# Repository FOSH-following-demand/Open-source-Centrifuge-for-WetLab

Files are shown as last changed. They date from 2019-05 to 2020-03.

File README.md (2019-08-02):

# An Open Source Centrifuge Design for wetlab based on Polyfuge v.1.0 Design
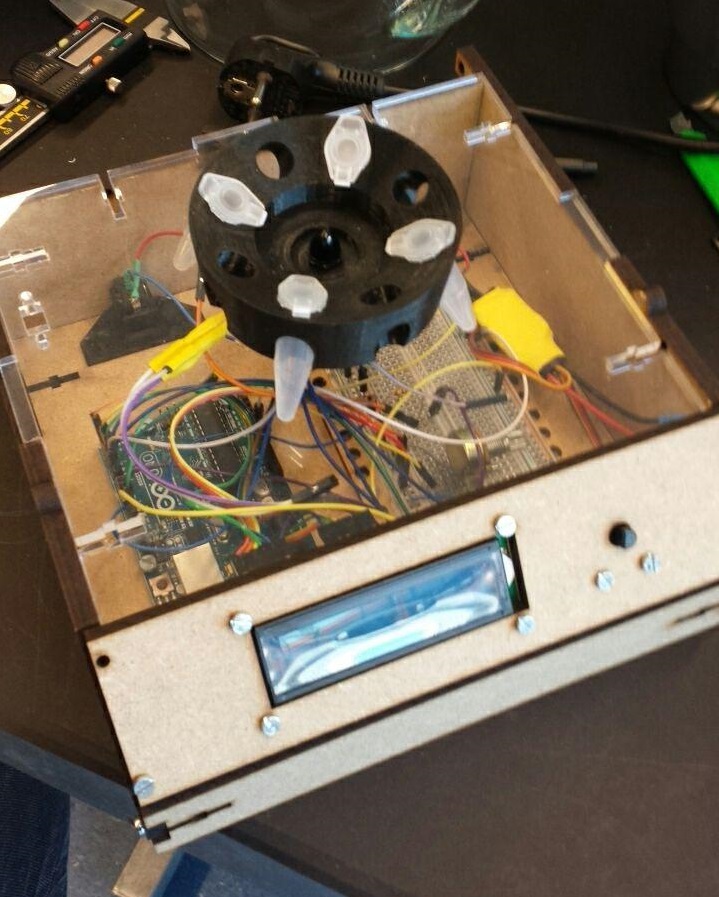
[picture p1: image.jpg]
centrifuge

## Hi! 😄 Welcome to the project
We are working on the design of an open hardware centrifuge based on the following questions:
- What can be improved in existing commercial centrifuges?
- What can be improved in already existing open hardware models?
- **Goal:** Design, improve a key feature based on the answers we got from these two questions.
#### Design approach:
- Replicate a model of open hardware centrifuges.
- Reverse engineer existing broken commercial centrifuges (fix them is possible as part of the process of learning how they work how, and how they can be improved).
- Propose and develop improvements.
    - Currently there are improvements to be made with regard to cooling and safety.

For more information on how we are tackling improvements, ideas, developments [look at the tests-experiments we are working on.](https://github.com/FOSH-following-demand/Open-source-Centrifuge-for-WetLab/tree/master/R%26D/test-cards)

### Current status of the project:
- [Collected data from users](https://docs.google.com/forms/d/1zq9jXL4ni4LQY3pLsI8-8exPlcGnMdUV0iULsLTLMks/viewanalytics). This one already points to interesting features to focus on that open hardware solutions don't consider like cooling, or automatic check  of proper balancing.
- [Ordered parts of Polyfuge version.](https://github.com/FOSH-following-demand/Open-source-Centrifuge-for-WetLab/blob/master/R%26D/Polyfuge-BOM.yml).

### Current phase: Concept generation and prototype design
Based on the research done about centrifuge usage we have defined [requirements](https://github.com/FOSH-following-demand/Open-source-Centrifuge-for-WetLab/tree/master/R%26D/Analysis) and target features to focus on.
## Links
- [Concept for solutions and test cards.](https://github.com/FOSH-following-demand/Open-source-Centrifuge-for-WetLab/tree/master/R%26D/test-cards)
- Find out the concept and associated test cases here.

## About project documentation and folders:
There are two sets of documentation in this repository:
- One that is external and relevant for users. This we try to document carefully and make it easy to understand to others outside the core team. Our final project documentation(the source) will be presented in [this format](https://fosh-following-demand.github.io/Open-source-Centrifuge-for-WetLab/). Be aware that is currently not finished as we haven't released the results yet.
- Another set of documentation is where we keep internal track of our tasks and progress. This one might be too detailed for external users, and even contributors. If you are interested in following up also this set of documentation you need to:
  - Use Atom editor.
  - And install the [.imdone](https://atom.io/packages/imdone-atom) package in Atom.
  - Clone the project.
  - Press `Alt+P`, and you should see the status of project management, tasks and priorities.

## References:
- [Value Proposition prototyping and testing](https://issuu.com/business.model.innovation/docs/vpd_sneakpeek/92)

# Progress documentation
| Week | Products | Call  | Status |
| --- | --- | ----- |---|
| Week 1 | GitHub repo + related_work.md + draft BoM | 1st call with mentor  | Done
| | Went to the lab and did usage research with scientist | | |
| Week 2 | Order BoM + Dev Plan | 2nd call with mentor  | Done |
| | Designed and sent form based on Usage analysis | | Done |
| Week 3 | Updates on development | 3rd call with mentor  | Done |
| | Collecting Data and studying other models (of big and small centrifuges) | | |
|  |Development planned updated, Concept generation | Not able to build because of delayed delivery of components | |
| Week 4 | Got enough results to focus on two key issues: safety and cooling, as we haven't found an open hardware solution with cooling mechanism. Safety and balancing still can be improved in the commercial centrifuges we analyzed | 4th called with mentor  | Done |
| Week 5  | Documenting new concepts and test cases, and updating ordering lists | 5th mentor called |Done|
| Week 6  | Architecture layout for peltier module, teard down and printing of polyfuge parts | 5th mentor called ||

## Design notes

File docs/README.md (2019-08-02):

# Open hardware centrifuge project
## Towards Polyfuge V2.0
  ::: Git repository

Clone, or download [our repo](https://github.com/FOSH-following-demand/Open-source-Centrifuge-for-WetLab) with all the source files.

  :::

A laboratory centrifuge is a piece of laboratory equipment, driven by a motor, which spins liquid samples at high speed. There are various types of centrifuges, depending on the size and the sample capacity. Like all other centrifuges, laboratory centrifuges work by the sedimentation principle, where the centripetal acceleration is used to separate substances of greater and lesser density.
To know more about centrifuges [read here](/SubContent/AboutCentrifuges.md).

## Current design based on Polyfuge V1.0
There are many OH centrifuge designs. For this project we decided to focus on one available open hardware design that was quite comprehensive and complete. This is why we decided to go for [the polyfuge](http://doublegene.com/), developed by doublegene. Find the [repo of Polyfuge V1.0 here](https://github.com/jasonwu2153/Polyfuge-A-DIY-Open-Source-Microcentrifuge-for-Everyone)

## Roadmap for improvements:
- **Design based on Arduino UNO**. We have faced difficulties with the Arduino NANO board specifically
- **Temperature control**. We are adding temperature control with a peltier module and a temperature sensor.
- **Increased speeds**. The current motor is limited in performance with regard to relative centrifuge force.

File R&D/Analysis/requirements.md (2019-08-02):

#Requirements

#### Samples
  - 'x' number of samples
  - sample volume range 'x' to 'z'
  - sample tubed spin under 'z' angle
  - Must be able to keep samples symetric in rotor

#### motor
  - 4700 minimum RPM
  - 10.000 maximum RPM
  - 'z' torque
  - Reliable motor speed with dynamic load variations (is there any specification for this?)
  - Isolation of the motor for
  - Cooling of the motor is required because motor can spin more than 20 mins.

#### Interface / Software
  - Be able to change speed (per how much RPM?)
  - Be able to change run time (per s ?)
  - Show current speed and time on screen

#### Safety
Robustness in this system implies that samples are well fixed to the holder, so that there  are no accidents.

  - Samples must be fixed to rotor
  - The spinning rotor is covered
  - The rotor can't spin while uncovered, can't be uncovered while spinning -> some kind of electric lock needed.
  - Noise limit should be limited to 'x' dB --> limit friction on moving parts.
  - Wiring and small components can't be exposed to moving parts.  
  - Electronic components must be well isolated so that there are no drops falling into them.

#### Embodiment
  - Easy to clean from microbe contamination --> smooth surface, no ridges.
  - Vibration resistant fasteners
  - footing should be stable on a tabletop.
  - Dampening of tremble from rotation is required  --> a counter weight at the bottom?

#### Construction
  - Be able to be put together locally like a kit (is this a requirement?)
  - Be able to be taken apart locally for repair
  -

# Considerations:
## Thermo couple
- One thermocouple should
- Calibration of the thermocouple

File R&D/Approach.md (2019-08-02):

#Documentation:40 Approach to design and development

# Goals of the first iteration
- We build one small centrifuge that kit design ready
- Ready for replication
- High quality documentation
- And reflection on how build the big centrifuge
-

# Approach:
- Case study: Define design questions and problems based on production system, usage, etc.
  - Use the centrifuge as a case study for open hardware products.
  - An example of a question is: why there are machines with 24 slots if daily use only involves 6 samples
  (For )
  - Includes checking patent infringement as well
  - Study current open hardware solution.

## Next steps design - development
- Define target specs:
  - Based on understanding the usability, scale of use, and manufacturing context.

The motor is the component that defines or constrains the whole design of the product, from a technical perspective.

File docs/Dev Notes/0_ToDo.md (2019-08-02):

# To Do:
## Minor issues
- [ ] Change potentiometer in the circuit
- [ ] Make new pcb shield to mount on the arduino

# New upgrades
- [ ] Redesign of the board and the centrifuge with the cooling module

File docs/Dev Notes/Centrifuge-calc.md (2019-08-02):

# Motor Calculation documentation
-[Calculations related to motor in spanish](http://biomodel.uah.es/tecnicas/centrif/centri_calc.htm)

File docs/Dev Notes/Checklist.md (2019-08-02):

# Checklist circuit build
- [ ] Voltage regulator
- [ ] Speed controller
- [ ] IRSensor
- [ ] Rotary Encoder

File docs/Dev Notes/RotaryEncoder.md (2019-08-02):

# Part: Rotary encoder
[Rotary Encoder for control panel with Arduino](https://www.google.com/search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)

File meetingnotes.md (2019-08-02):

## TU Delft meeting 5

- rushing to order everything before deadline and doing calculations for requirements
- tension between desired and possible model, 2 months is little time!!
- In particular, due to delays in ordering parts, and need more time for planning accordingly
- Feedback for next time: better to anticipate at least 1 month do money deadline, and 'force' teams to have clear goals and stages complete
- Will share pictures on work today through Slack

## TU Delft meeting 4

- got space to work!
- ordered parts, billing pending to be sent to Andre

- Discussed ideas for testing and put them into issues: cooling, sensing of cooling, secure parts during movement
- design test to be done, mechanical engineer joining project

- Possible outcome for BFOSH: documentation for hw is better if it's kept simple at first (journaling) instead of OPEN ALL in t=0

- Next: get attention to the issues for user input, keep testing and dev

Next meeting: june 21

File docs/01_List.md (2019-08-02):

# DIY and Open Source Centrifuge list

### [Home made centrifuge](https://www.youtube.com/watch?v=EWWUqkEXJUE)

- [Thingiverse project](https://www.youtube.com/redirect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)

### OpenFuge
- [OpenFuge isntructables](https://www.instructables.com/id/Centrifuge/).
- [OpenFuge Repository](https://www.instructables.com/id/Centrifuge/)
- Very well documented step by step with pictures and breadboard visual schematics.

### BHA Centrifuge
- [BHA Centrifuge Repository](https://github.com/BioHackAcademy/BHA_Centrifuge)

### Polyfuge
- [Polyfuge repository](https://github.com/jasonwu2153/Polyfuge-A-DIY-Open-Source-Microcentrifuge-for-Everyone)

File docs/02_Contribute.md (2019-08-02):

# Contributing guidelines
## Hi! 😸 Thank you very much for reaching us out.
We are looking for contributions of different kind that ranges from incidental but meaningful contributions to extended and close collaboration.

## Things to consider:
- We are focusing in this first iteration on small centrifuge design of 15 ml.
- We are using a reference open hardware project to replicate, test, hack and improve if possible.
-

## These is a list of things you can do in order to contribute to the project:
### User feedback:
- If you are a user of this equipment you can (https:[fill in this form]//docs.google.com/forms/d/e/1FAIpQLScyTZIfLe0GmoX6rdi7wdyzSNGVoP2hBOGGEqeAVn0CZmRDTQ/viewform) and share it with your colleagues.

### Opening github issues for design improvements you have been thinking about:
We always consider each improvement as a hypothesis that needs to be tested.
You can also point to videos, documentation and solutions that support the hypothesis/idea you have in mind. [See this example](https://www.youtube.com/watch?v=9Cuh2msd2lo) as a style guide for test setup.
- If you have ideas about centrifuge solutions features, open an issue and describe the concept/hypothesis considering the following:
  1. How this feature improves the centrifuge design considering:
  1.1. Pains you have already had in your previous experience.
  1.2. Gains your idea has.

  2. Description of the concept.
  3. Preferably describe a test case/experiment [by using the following  markdown template](https://github.com/FOSH-following-demand/Open-source-Centrifuge-for-WetLab/blob/master/R%26D/test-cards/README.md).
  - [You can find an example here:](https://github.com/FOSH-following-demand/Open-source-Centrifuge-for-WetLab/blob/master/R%26D/test-cards/Cooling-led-2.md)

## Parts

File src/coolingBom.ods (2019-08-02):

Part | Description | Quantity | Purchase Link | status | Function
Relays |  |  |  | check at home | 1 for each fan(2), one for the pelter
on/off | On Off switch with power supply |  | https://www.amazon.com/Switch-Supply-Outlet-Socket-Printer/dp/B07B8D1M17 | not ordered
Power supply |  |  |  | in stock
 | N-MOSFET Driver / Output Module |  | https://www.freetronics.com.au/collections/modules/products/n-mosfet-driver-output-module |  | This high-power N-MOSFET module lets you switch high-current loads using a tiny microcontroller. Perfect for controlling that set of traffic lights mounted in your living room! Works brilliantly for automotive projects such as switching high-power 12V lights and high wattage LEDs.

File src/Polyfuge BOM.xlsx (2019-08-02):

Quantity | Manufacturer/Vendor | Part Number | Link | Description
Electrical
1 | Arducam | C0048 | https://www.amazon.com/Arducam-Display-Controller-Character-Backlight/dp/B019D9TYMI | Main LCD for UI display
1 | uxcell | a14011500ux0042 | https://www.amazon.com/Position-Degree-Rotary-Encoder-Button/dp/B00KHTLWU6 | Rotary encoder for control
1 | Elegoo | EL-CB-004 | https://www.amazon.com/Arduino-Elegoo-board-ATmega328P-compatible/dp/B071NMBP4S | Arduino Nano microcontroller
1 | FBApayipa | B01N2U8PK0 | https://www.amazon.com/FBApayipa-Solder-Rocker-Switch-Toggle/dp/B01N2U8PK0?s=electronics | Boat Rocker Switch for ON/OFF
1 | GenBasic | 4330127279 | https://www.amazon.com/GenBasic-Female-Solderless-Breadboard-Prototyping/dp/B01L5ULRUA?s=electronics | Pack of F to F headers for circuit connections
1 | BLHeli | B01D3127NU | https://www.amazon.com/Hobbypower-BLHeli-Controller-QAV210-Quadcopter/dp/B01D3127NU | 12A ESC for centrifuge motor
1 | EMAX | B00SYH8NXC | https://www.amazon.com/Crazepony-MT2204-Brushless-Multirotor-Quadcopter/dp/B00SYH8NXC | Brushless motor for centrifuge rotor
1 | Orcity | B01MQ48T2V | https://www.amazon.com/2-54mm-Breakaway-Female-Connector-Arduino/dp/B01MQ48T2V | Pack of breakaway M and F pins for boards
1 | SUNKEE | 1361783 | https://www.amazon.com/SUNKEE-TCRT5000L-TCRT5000-Reflective-Transistor/dp/B008A3VP6M | IR sensor for lid safety interlock
1 | ALED LIGHT | B013SSU92Y | https://www.amazon.com/gp/product/B013SSU92Y/ref=oh_aui_detailpage_o00_s00?ie=UTF8&psc=1 | 2A Power adapter (US)
1 | eBoot | EXPSFD005794 | https://www.amazon.com/eBoot-LM2596-Converter-3-0-40V-1-5-35V/dp/B01GJ0SC2C | LM2596 Voltage Regulator
1 | uxcell | a15071300ux0341 | https://www.amazon.com/a15071300ux0341-Terminals-Potentiometer-Adjustable-Resistor/dp/B015AUI2TK?s=industrial | 200 Ohm trim potentiometer for LCD contrast
2 | E-Projects | B071439J4B | https://www.amazon.com/Projects-10EP51410K0-10k-Resistors-Pack/dp/B071439J4B?s=industrial | 10k Ohm resistors for circuit board
1 | E-Projects | B0725G2WM7 | https://www.amazon.com/Projects-100EP514100R-100-Resistors-Pack/dp/B0725G2WM7?s=industrial | 100 Ohm resistor for circuit board
1 | DoubleGene | N/A | See open-source files | Open-Source Polyfuge PCB
1 | ZRAMO | UK-HM023 | https://www.amazon.com/ZRAMO-5-5x2-1mm-Adapter-Connector-Security/dp/B06XXCTNX5 | Barrel Jack adapter for power supply
Mechanical
1 | DoubleGene | N/A | See open-source files | Open-Source Polyfuge centrifuge rotor
1 | DoubleGene | N/A | See open-source files | Open-Source laser cut or 3D-printed frame components
50 | McMaster-Carr | 92005A128 | https://www.mcmaster.com/#catalog/123/3033/=178lzno | 20mm M3 Steel Philips Rounded Screw
50 | McMaster-Carr | 90591A250 | https://www.mcmaster.com/#catalog/123/3210/=178m0rv | M3 Steel Hex Nut
10 | McMaster-Carr | 91166A210 | https://www.mcmaster.com/#catalog/123/3254/=178m1nk | M3 Steel Washer
50 | McMaster-Carr | 90133A005 | https://www.mcmaster.com/#standard-rubber-washers/=19akq7h | M3 Rubber Washer
4 | McMaster-Carr | 92005A120 | https://www.mcmaster.com/#machine-screws/=17ptixe | 10mm M3 Steel Philips Rounded Screw
4 | ROK Hardware | SCB03-144 | https://www.amazon.com/Rok-Hardware-Cabinet-Furniture-Diameter/dp/B00K6RZ9Q2 | Furniture bumpers to dampen vibrations on bottom of unit
Other (Raw Materials for Frame and Rotor)
1 | Hatchbox | B00J0ECR5I | https://www.amazon.com/HATCHBOX-3D-Filament-Dimensional-Accuracy/dp/B01N53KX79 | PLA Filament for printing rotor and encoder knob (use 20% infill or higher)
24" x 20" | McMaster-Carr | 8505K748 (https://www.mcmaster.com/) | https://www.mcmaster.com/#clear-impact-resistant-plastic/=1c43uxq | 3/16" Acrylic for frame pieces (purchase from local companies/stores for cheaper prices)

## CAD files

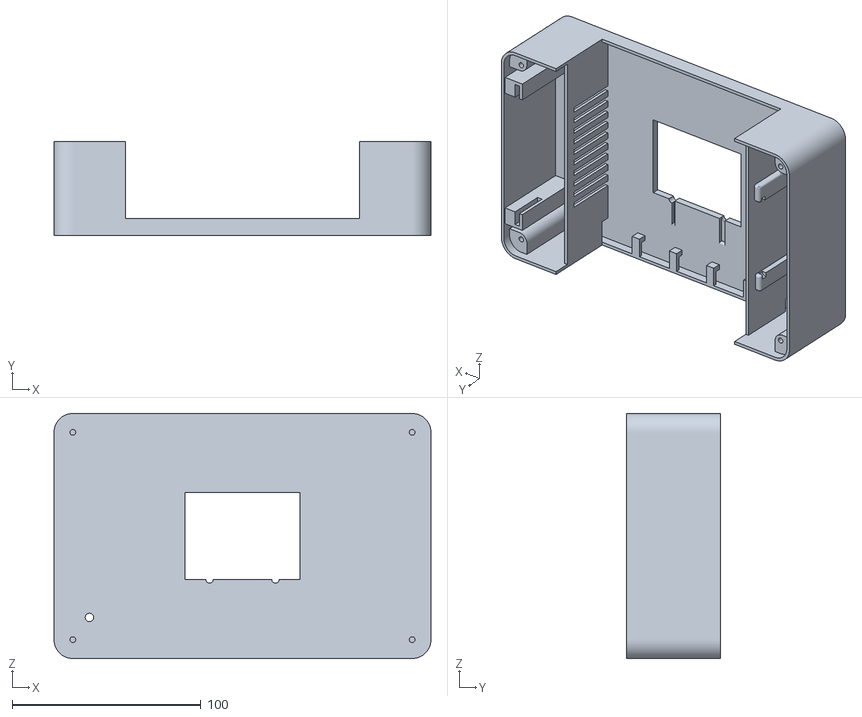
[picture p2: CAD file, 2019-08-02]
R&D/design-tests-setups/Cooling-lid-02/mini-fridge/cover_2.stl
200.0 x 50.0 x 130.0

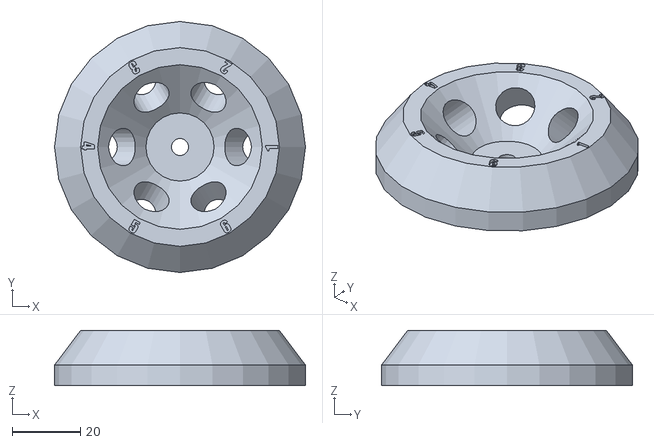
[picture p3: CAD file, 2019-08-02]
R&D/design-tests-setups/Cooling-lid-02/V2_Rotor.stl
73.6 x 73.6 x 16.1

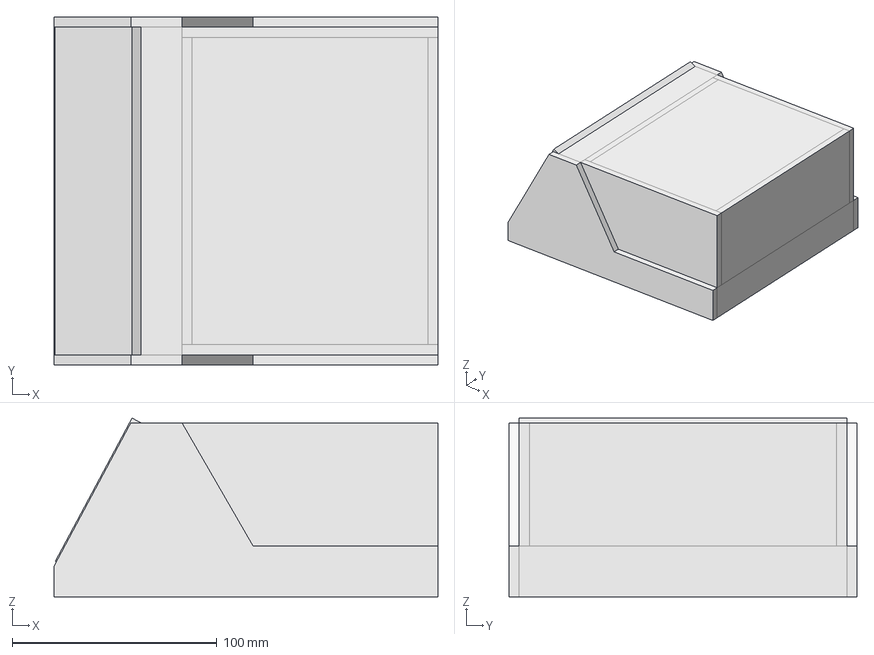
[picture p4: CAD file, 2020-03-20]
R&D/polyfuge 1.2/sheet model_no cut.FCStd
187.5 x 170.0 x 87.4 mm

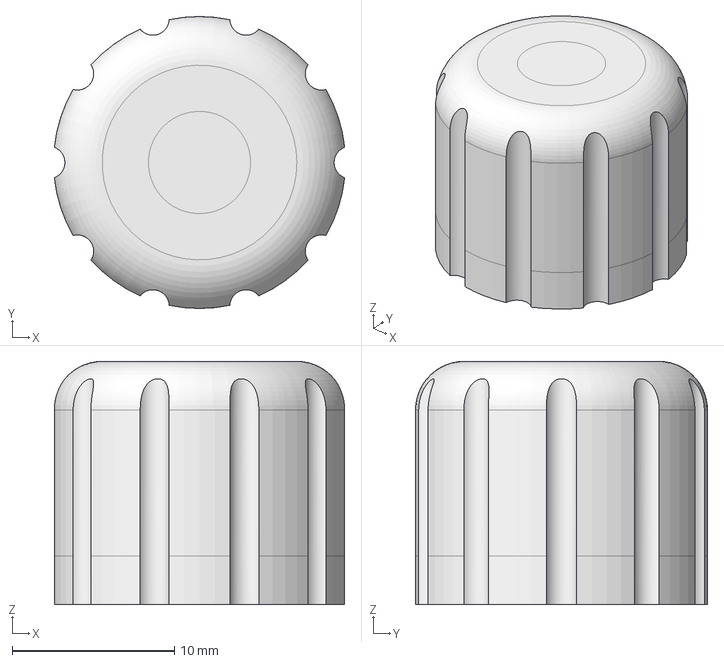
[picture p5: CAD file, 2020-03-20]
src/knob v3.FCStd
17.9 x 18.0 x 15.0 mm

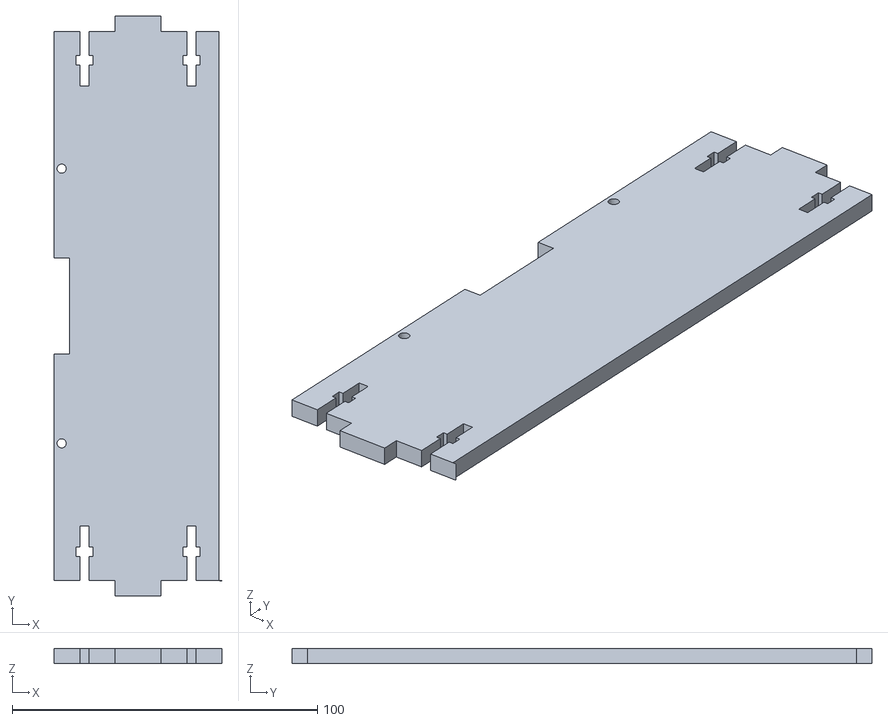
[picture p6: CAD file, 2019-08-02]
src/Polyfuge STL Files (For 3D-Printing)/Pieces/Top Back Panel.stl
55.0 x 190.0 x 5.00

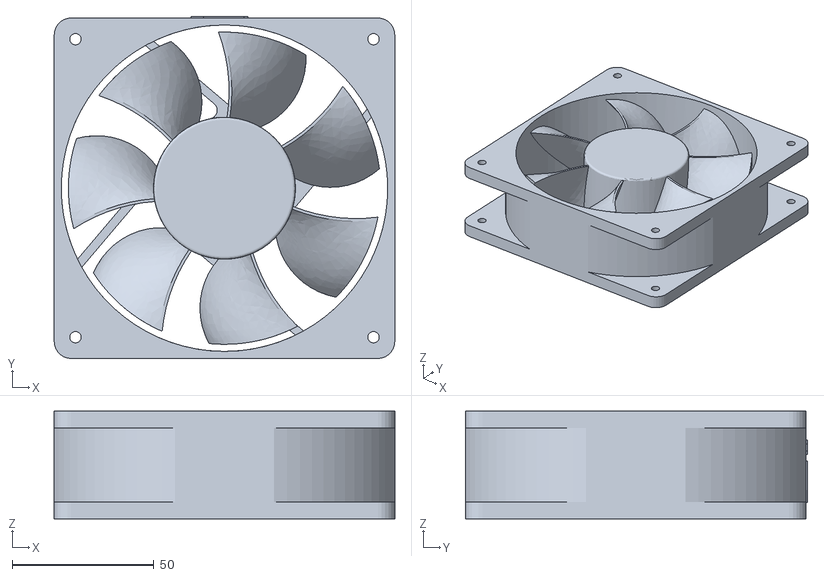
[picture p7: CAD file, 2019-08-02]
R&D/design-tests-setups/Cooling-lid-02/4-inch-fan.stl
120.0 x 120.5 x 38.0

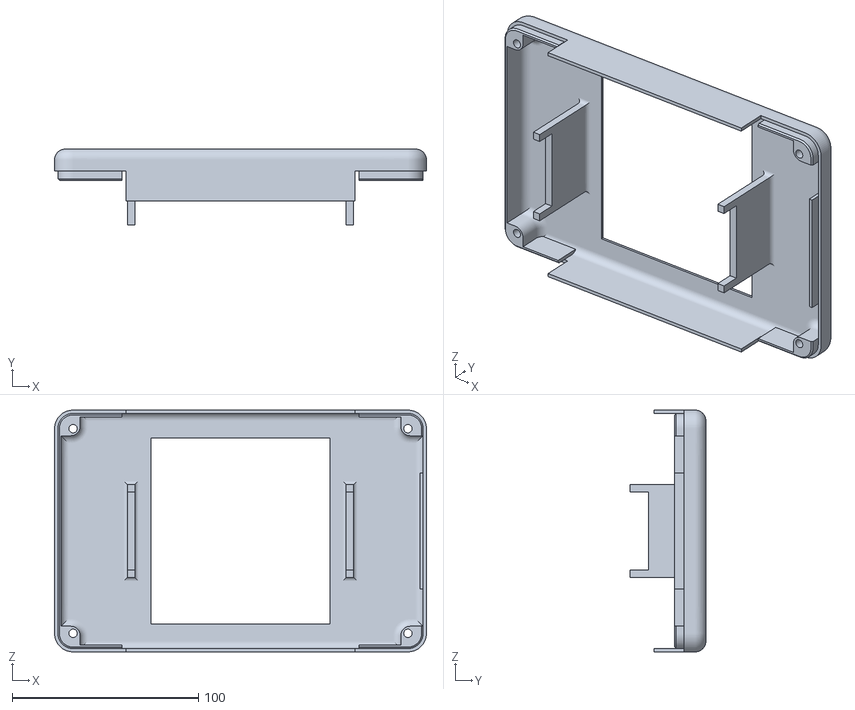
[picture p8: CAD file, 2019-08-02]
R&D/design-tests-setups/Cooling-lid-02/mini-fridge/cover.stl
200.0 x 40.8 x 130.0

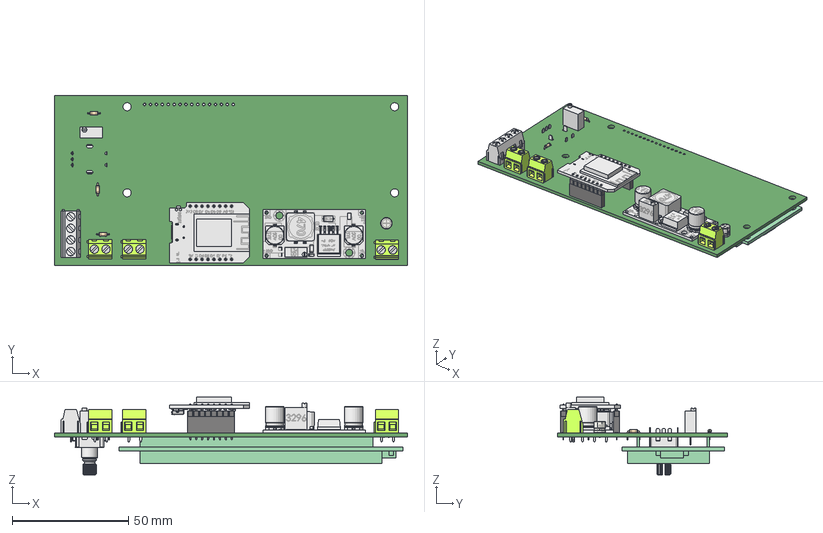
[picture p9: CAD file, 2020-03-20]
R&D/polyfuge 1.2/PCB.FCStd
151.8 x 73.0 x 33.4 mm

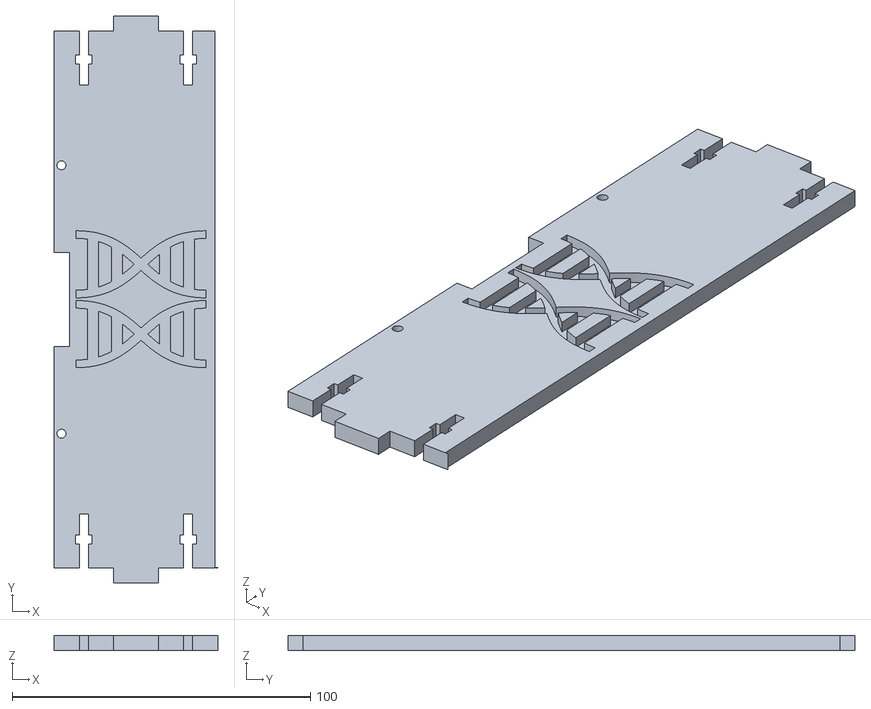
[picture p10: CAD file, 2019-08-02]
src/Polyfuge STL Files (For 3D-Printing)/Pieces/Top Front Panel (With Design DoubleGene).stl
55.0 x 190.0 x 5.00

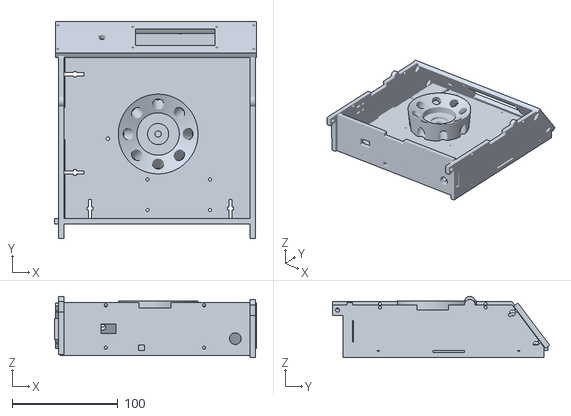
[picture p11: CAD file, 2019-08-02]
R&D/design-tests-setups/Cooling-lid-02/polyfuge-ref4.stl
191.0 x 205.6 x 58.0

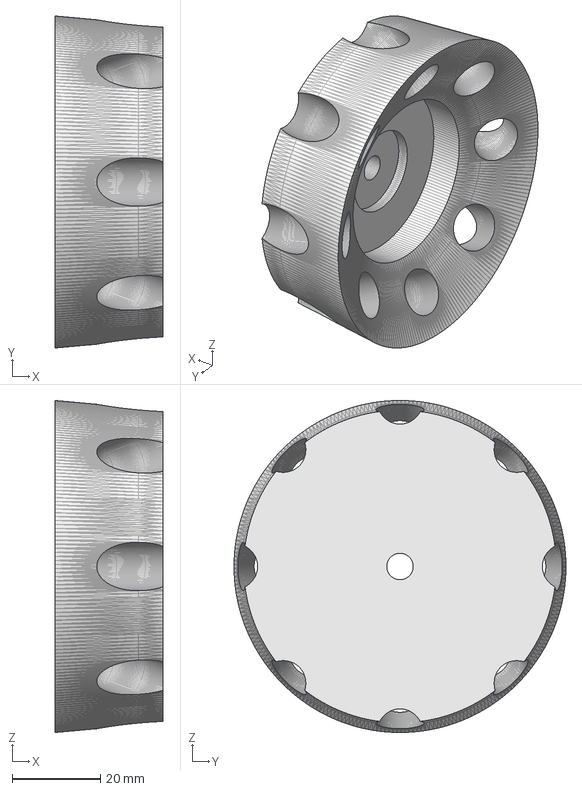
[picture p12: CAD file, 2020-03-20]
R&D/polyfuge 1.2/rotor.FCStd
24.4 x 75.3 x 75.3 mm

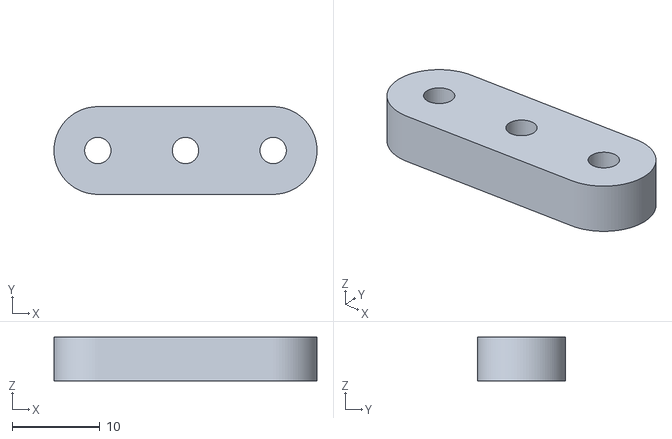
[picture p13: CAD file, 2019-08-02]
src/Polyfuge STL Files (For 3D-Printing)/Pieces/Side Panel Hinge.stl
30.0 x 10.0 x 5.00

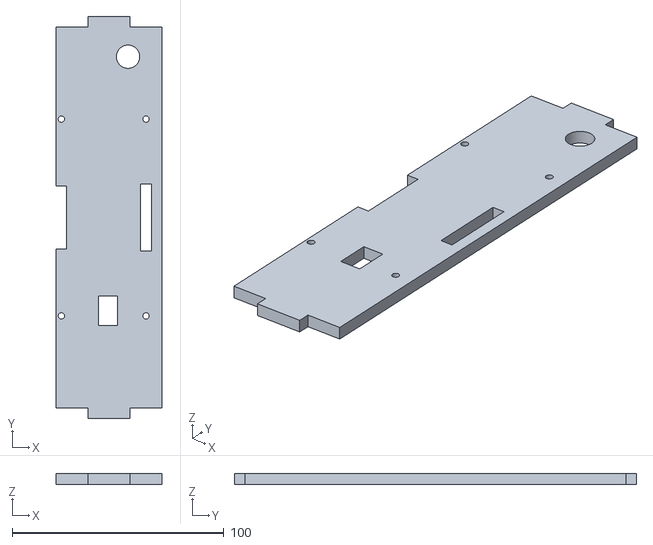
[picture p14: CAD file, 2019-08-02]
src/Polyfuge STL Files (For 3D-Printing)/Pieces/Back Panel.stl
50.0 x 190.0 x 5.00

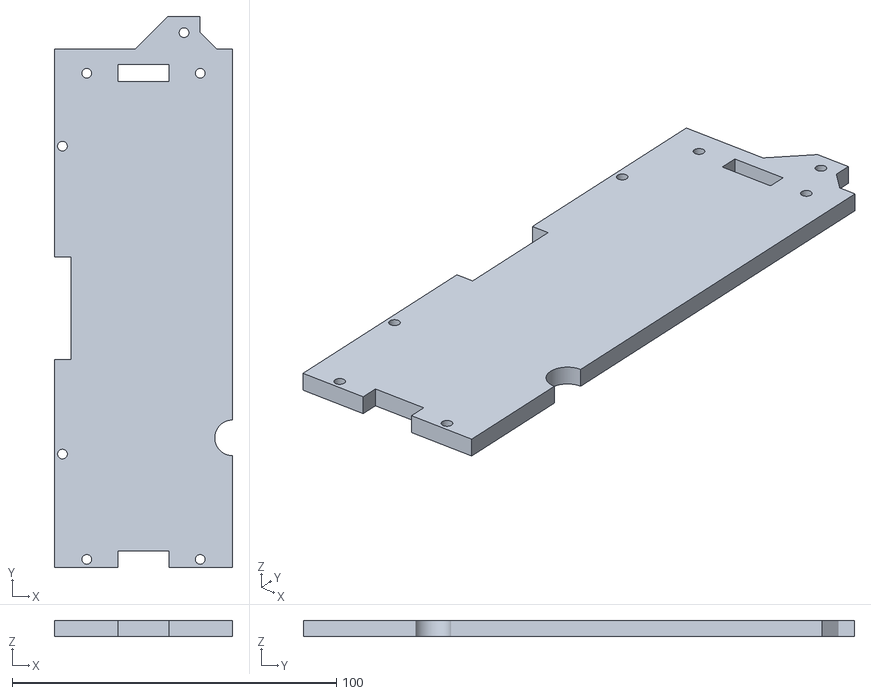
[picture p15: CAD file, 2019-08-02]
src/Polyfuge STL Files (For 3D-Printing)/Pieces/Top Side Panel (NO IR BLOCKER).stl
55.0 x 170.0 x 5.00

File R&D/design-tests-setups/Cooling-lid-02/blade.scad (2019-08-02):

//!OpenSCAD

// Thickness of the blade overall
Overall_Thickness = 6.2;
// Outer Diameter with blades (default 37mm)
Outer_Diameter_Blades = 37;
// Thickness of the blades (default 1mm)
Thickness_Blades = 0.8;
// Amount of blades (default 9)
Amount_Blades = 6;
// The angle with which the blades are bowed (default 50°)
Bowing_Blades = 45;
// The angle of the blades (default 50°)
Angle_Blades = 45;
// Inner Diameter of the Body (default 22.6mm)
Inner_Diameter_Body = 10;
// Thickness of the body parts (default 1.2mm)
Thickness_Body = 1;
// The diameter of the axle hole (default 1.8mm)
Axle_Diameter = 2;

// Circle Resolution
$fn = 64;

// Some helping parameter
Length_Blades = (Outer_Diameter_Blades - Inner_Diameter_Body) / 2;
Remaining_Angle = (90 - Bowing_Blades) / 2;
Radius_Blades = Overall_Thickness / (cos(Remaining_Angle) - sin(Remaining_Angle));
translate([0, 0, (Overall_Thickness / 2)]){
  union(){
    difference() {
      union(){
        difference() {
          cylinder(r1=(Inner_Diameter_Body / 2 + Thickness_Body), r2=(Inner_Diameter_Body / 2 + Thickness_Body), h=Overall_Thickness, center=true);

          translate([0, 0, (Thickness_Body / 2)]){
            cylinder(r1=(Inner_Diameter_Body / 2), r2=(Inner_Diameter_Body / 2), h=(Overall_Thickness - Thickness_Body), center=true);
          }
        }
        translate([0, 0, (-1 * (Overall_Thickness / 2 - (Thickness_Body + 0.5)))]){
          cylinder(r1=(Axle_Diameter / 2 + 1), r2=(Axle_Diameter / 2 + 1), h=1, center=true);
        }
      }

      translate([0, 0, (-1 * (Overall_Thickness / 2 - 2.7))]){
        cylinder(r1=(Axle_Diameter / 2), r2=(Axle_Diameter / 2), h=5, center=true);
      }
    }
    intersection() {
      for (i = [0 : abs(360 / Amount_Blades) : 360]) {
        rotate([0, 0, i]){
          translate([((Inner_Diameter_Body + Length_Blades) / 2), 0, 0]){
            rotate([0, 90, 0]){
              Mean_X = Radius_Blades * (cos(Angle_Blades) * cos((Bowing_Blades / 2)));
              Mean_Y = Radius_Blades * (sin(Angle_Blades) * cos((Bowing_Blades / 2)));
              translate([(-1 * Mean_X), (-1 * Mean_Y), 0]){
                for (j = [Angle_Blades - Bowing_Blades / 2 : abs(Bowing_Blades / 20) : Angle_Blades + Bowing_Blades / 2]) {
                  translate([(Radius_Blades * cos(j)), (Radius_Blades * sin(j)), 0]){
                    rotate([(-1 * (atan((sin(j) * Radius_Blades - Mean_Y) / ((Length_Blades + Inner_Diameter_Body) / 2 + Thickness_Body)))), 0, 0]){
                      rotate([0, 0, j]){
                        cube([Thickness_Blades, Thickness_Blades, Length_Blades], center=true);
                      }
                    }
                  }
                }

              }
            }
          }
        }
      }

      cylinder(r1=(Outer_Diameter_Blades / 2), r2=(Outer_Diameter_Blades / 2), h=Overall_Thickness, center=true);

    }
  }
}

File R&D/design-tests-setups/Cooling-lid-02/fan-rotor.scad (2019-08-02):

module rotor(){
  translate([18,258,0])
  import("V2_Rotor.stl", convexity=3);
  $fn=64;
  for(i=[0:5]){
    rotate(i*60,[0,0,1])
    translate([0,25,0])
    rotate([0,20,30])cube([2,13,17]);
  }
}

/* rotor(); */
module sample(){
  difference(){
    cylinder(h=20, r=9, center=true);
    cylinder(h=30, r=5.6, center=true);
  }
}

for(i=[0:5]){
  rotate(i*60,[0,0,1])
  union(){
  translate([-25,0,2])rotate([0,45,0])sample();
  translate([12,20,0])rotate([0,-60,0])cube([2,20,27]);
  }
}


module fan(){
  import("4-inch-fan.stl");
}

/* scale(0.85)translate([0,0,0])color("DarkSlateGray",0.25)fan(); */

/* translate([0,60,0])
union(){
sample();
translate([12,-5,2])rotate([0,-50,0])cube([2,27,20],center=true);
} */

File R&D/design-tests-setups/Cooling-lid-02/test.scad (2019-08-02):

module cooling_surface(half){
    module object(){
    difference(){
    color("red")
    difference(){
    cylinder(h = 30, r1 = 42, r2 = 42, center = true);
    translate([0,0,-12])
    cylinder(h = 50, r1 = 40, r2 = 40, center = true);
    }
    cube([42,42,40], center=true);
  }
}
    if (half==true){
      difference(){
      object();
      cube([90,90,90]);
      }
    }
    else{
      object();
    }
}

module peltier(){
  color("grey")
  cube([40,40,4], center=true);
}

module fan(){
  import("4-inch-fan.stl");
}

// cooling_surface();
module rotor(){
  translate([18,258,0])
  import("V2_Rotor.stl", convexity=3);
}

module lid(){
  rotate([90,0,0])
  translate([0,-50,0])
  import("mini-fridge/cover.stl");
  translate([0,0,-53])
  rotate([90,0,0])
  import("mini-fridge/cover_2.stl");
}

module polyfuge(){
  import("polyfuge-ref4.stl");
}


/* difference(){ */
  union(){
  rotor();
  translate([0,0,10])cooling_surface();
  translate([0,0,27])peltier();
  union(){
    scale(0.85)translate([0,0,80])color("DarkSlateGray")fan();
    translate([0,0,80])lid();
  }
  translate([95,-80,-30])color("DodgerBlue")polyfuge();

  }
/* translate([-50,0,40])cube([100,150,100],center=true);
} */

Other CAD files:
src/knob3.stl
src/Polyfuge STL Files (For 3D-Printing)/Pieces/IR Blocker.stl
src/Polyfuge STL Files (For 3D-Printing)/Pieces/Base.stl
src/Polyfuge STL Files (For 3D-Printing)/Pieces/Top Panel.stl
src/Polyfuge STL Files (For 3D-Printing)/Pieces/Front Panel.stl
src/Polyfuge STL Files (For 3D-Printing)/Pieces/Rotor V2.stl
src/Polyfuge STL Files (For 3D-Printing)/Pieces/Rotor.stl
src/Polyfuge STL Files (For 3D-Printing)/Pieces/Side Panel (No Mounts).stl
src/Polyfuge STL Files (For 3D-Printing)/Pieces/Side Panel (Optical).stl
src/Polyfuge STL Files (For 3D-Printing)/Pieces/Side Panel (USB).stl
src/Polyfuge STL Files (For 3D-Printing)/Pieces/Top Side Panel (IR Blocker).stl
src/Polyfuge STL Files (For 3D-Printing)/Pieces/Top Top Panel.stl
src/Polyfuge STL Files (For 3D-Printing)/Pieces/knob.stl

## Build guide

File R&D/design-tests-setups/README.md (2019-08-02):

# TEST:50 Name of the test
#### Name: Person
#### Date:

## 1. Concept-for-solution:
Describe what is your solution-hypothesis/feature and how you think it should works.

## 2. To verify that we will do the following test:
## Checklist for experiment:
- [ ] Use an image to explain the setup
- [ ] What are the materials needed.
- [ ] Which materials need to be ordered
- [ ] How expensive is it roughly
Describe the experiment/ test as detailed as possible.

## 3. What are you going to measure
## Checklist:
- [ ] How much data
- [ ] How much time does it takes

## 4. Your experiment is successful if:
Define a target threshold, set of criterion that validates or invalidates the experiments.

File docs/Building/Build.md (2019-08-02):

# Building

## Circuit Build
::: tip
Be aware that this design will be also developed in a PCB.

But you can also replicate it using a regular breadboard.

 :::

Centrifuge schematic

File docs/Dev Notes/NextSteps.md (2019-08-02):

# Next Step Assembly
- Add the code for the sensor to run the motor

## Notes for new design
- Bigger power supply
- New Breakboard for powersupply that powers bigger and cooling module.
- New circuit board for the polyfuge with Arduino Uno

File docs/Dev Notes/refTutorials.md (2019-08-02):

# References and tutorials
## LCD tutorial

- [Arduino LCD Tutorial](https://howtomechatronics.com/tutorials/arduino/lcd-tutorial/).

- [LM 2596 DC -DC Buck converter | Adjustable step down module | specifications -Application](https://www.youtube.com/watch?v=QPntXt8Ea3s).

- [How does a brushless motor works](https://www.youtube.com/watch?v=uOQk8SJso6Q)

## Motor control
- [Control brushless motor with Arduino](https://www.youtube.com/watch?v=DTOK6CgXRXg)
- [Brushless motor control with Arduino Nano](https://www.youtube.com/watch?v=neU6vPDGOBA)

## Voltage regulator for board
The board takes a maximum of 5.5 Volts, there fore a voltage regulator is needed. We are currently using a [LM2596 Voltage Regulator](https://www.minikits.com.au/LM2596-PSU-01).
- [Video review of the regulator](https://www.youtube.com/watch?v=6LTxJWsn1HQ)

## Cooling module with arduino
- [Peltier Controlled From An Android App](https://create.arduino.cc/projecthub/abetoo/peltier-controlled-from-an-android-app-e59617).
- [Fridge project with peltier part 1](https://www.youtube.com/watch?v=1Kp_yWY2tdU).
- [Fridge project with peltier part 2](https://www.youtube.com/watch?v=BHFI9nGY8Qs).
- [Relay module for arduino](https://randomnerdtutorials.com/guide-for-relay-module-with-arduino/).
- [Arduino temperature controller](https://www.instructables.com/id/Arduino-Temperature-Controller/)

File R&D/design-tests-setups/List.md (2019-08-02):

In this document we collect all the hypothesis related to product improvements, pains and gains from our analysis. This analysis includes the state of the art of current open hardware and proprietary centrifuges, as wel.

#Hypothesis:30 ## Doubled motor centrifuge
A model like the one in the drawing can be more cost effective...

#TEST:50 Calculate costs for doubled motr centrifuge
Assuming the following

#Hypothesis:0 ## An industrial standard casing that can be adapted re-purposed
- There might be casings, and chasis solutions that are generic and can be used for the centrifuge.

#Hypothesis:20 ## Casing made of [vacuum forming](https://en.wikipedia.org/wiki/Vacuum_forming)
- We can make already an improvement to this centrifuge by changing the casing design.

#TEST: ## Can we accurately balance a rotor with one very sensitive sensor?
- Angle sensor can be a good potmeter with a rod that brushes the bottom of the rotor.
- The rotor makes one slow spin before turning on the program, any change in the potmeter's resistance means that the rotor isn't balanced.
- Or we could have it reading throughout operation of the centrifuge.
- Or two springloaded potmeters opposite of eachother, and the difference is calculated.
- Other sensor option: contact sensor
-

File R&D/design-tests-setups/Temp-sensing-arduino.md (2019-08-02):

# Temperature Sensing with K+Thermocouple and Arduino
[See the video here](https://www.youtube.com/watch?v=0KJ8H_SUWp0)

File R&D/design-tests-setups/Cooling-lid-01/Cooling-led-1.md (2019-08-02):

#TEST:30 ## Cooling led before centrifuging
#### Name: Jose
#### Date: 7-6-2019

## 1. Concept-for-solution:
A peltier element `3` can be placed on a metal surface `1` that is in direct contact with the samples reservoir`4`. The samples cooled via this setup and the cooling mechanism decouples before the centrifuge starts to rotate.

## 2. To verify that we will do the following test:
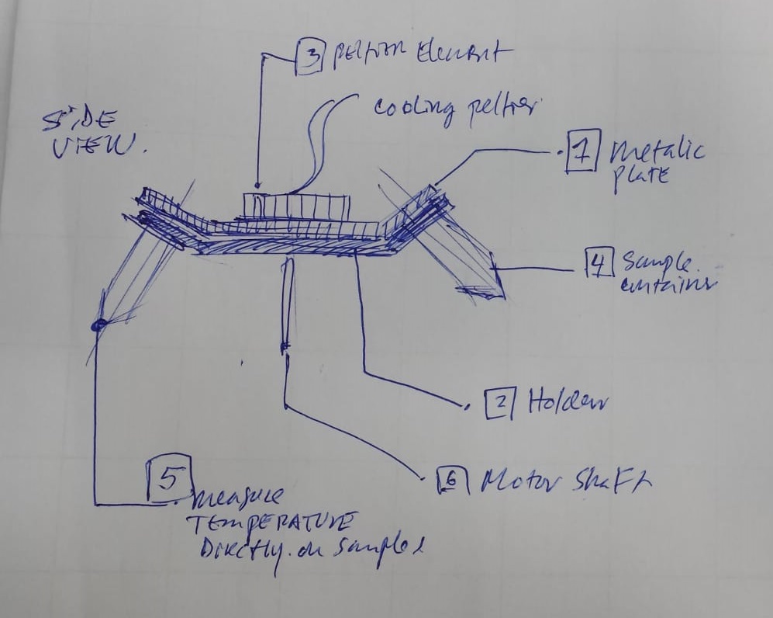
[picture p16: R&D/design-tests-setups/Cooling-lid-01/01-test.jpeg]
experiment

- The setup is going to be isolated in a box.
- Metalic plate is in contact with each sample.
- There are 12-24 samples in the test case.
- A sensor senses ambient temperature in the box.
- Another sensor measures directly on one of the samples.

### Checklist for experiment:
- [ ] Use an image to explain the setup
- [ ] What are the materials needed.
  - temperature sensor to measure directly the sample reservoir
- [ ] Which materials need to be orderedpre
- [ ] How expensive is it roughly

## 3. What are you going to measure
- Measure inner temperature in sample
  - Must calculate the inner temperature of the sample, not the outer of  the sample reservoir. Calculate this based on the material.
  - Heat transfer considerations.
- Measure samples also after being centrifuged.

## 4. Your experiment is successful if:
- The temperature doesn't go bellow 4 degrees
- The temperature stays stable for

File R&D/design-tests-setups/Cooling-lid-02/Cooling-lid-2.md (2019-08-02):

# Peltier on led floating close to sample
#### Name: Santosh
#### Date:

## 1. Concept-for-solution:
The peltier doesn't touch the sample. It starts cooling when it rotates, air is cooled with the peltier and that air cools the sample. The concept the faster it rotates the faster it will cool down. Thermo couple will measure the temperature and will compare to the set value of temperature.
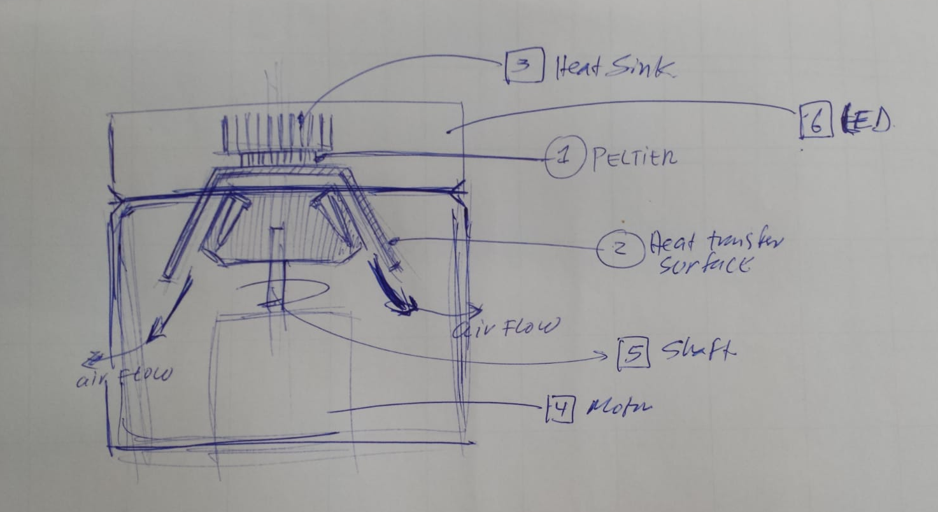
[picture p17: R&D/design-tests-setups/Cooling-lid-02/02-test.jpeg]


## 2. To verify that we will do the following test:
## Checklist for experiment:
Based on the temperature range (what thermo couple is able to measure), we decide the type of it.

## Materials:
- [K type](https://en.wikipedia.org/wiki/Thermocouple), should do the job. Is the cheapest and most commonly used.
- [Cooling kit that incldes peltier, heatsink, fan,and more.](https://www.amazon.de/dp/B01M5DX5KT?tag=tv-auto-20)
- Power Supply (Not specified yet)
## 3. What are you going to measure
## Checklist:
- [ ] How much data
- [ ] How much time does it takes

## 4. Your experiment is successful if:
- We are able to cool the samples in less than 5 minutes to the target temperature set by the user.
- The temperature of the samples remain constant.

# Implementation notes
## Usage considerations:
3. The chamber needs to be already cooled before we put the samples.
2. Therefore in this concept, the user would have to first cool the system,
3. Then open the led to place the sample.
4. And start centrifuging.

## Architecture and layout model test:


## How to measure temperature
**Options/Ideas:**

a. Wireless temperature sensor touching one of the samples, mounted on the rotor.

b. Meausre right after the cool process placing thermo coupler on top of the sample

## References
- [Building your own mini fridge](https://hackaday.com/2015/04/03/building-your-own-mini-fridge/).
- [Peltier Thermoelectric Cooler](https://www.youtube.com/watch?v=jCMDuTR-mqY&t=47s)
- [Peltier Module Cooling](https://www.youtube.com/watch?v=9Cuh2msd2lo).

# Ideas


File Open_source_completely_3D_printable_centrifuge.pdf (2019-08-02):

Instruments 2019, 3, 30; doi:10.3390/instruments3020030 | www.mdpi.com/journal/instruments

Article

# Open Source Completely 3-D Printable Centrifuge

Salil S. Sule ¹, Aliaksei L. Petsiuk ² and Joshua M. Pearce ²,3,4,*

1 | Department of Mechanical Engineering–Engineering Mechanics, Michigan Technological University,
| Houghton, MI 49931, USA; ssule@mtu.edu
2 | Department of Electrical & Computer Engineering, Michigan Technological University, Houghton, MI
| 49931, USA; apetsiuk@mtu.edu
3 | Department of Material Science & Engineering, Michigan Technological University, Houghton, MI 49931,
| USA
4 | Department of Electronics and Nanoengineering, School of Electrical Engineering, Aalto University, Espoo,
| FI-00076, Finland
* | Correspondence: pearce@mtu.edu or joshua.pearce@aalto.fi; Tel.: +01-906-487-1466

Received: 13 May 2019; Accepted: 15 May 2019; Published: 18 May 2019

Abstract: Centrifuges are commonly required devices in medical diagnostics facilities as well as scientific laboratories. Although there are commercial and open source centrifuges, the costs of the former and the required electricity to operate the latter limit accessibility in resource-constrained settings. There is a need for low-cost, human-powered, verified, and reliable lab-scale centrifuges. This study provides the designs for a low-cost 100% 3-D printed centrifuge, which can be fabricated on any low-cost RepRap-class (self-replicating rapid prototyper) fused filament fabrication (FFF)-or fused particle fabrication (FPF)-based 3-D printer. In addition, validation procedures are provided using a web camera and free and open source software. This paper provides the complete open source plans, including instructions for the fabrication and operation of a hand-powered centrifuge. This study successfully tested and validated the instrument, which can be operated anywhere in the world with no electricity inputs, obtaining a radial velocity of over 1750 rpm and over 50 N of relative centrifugal force. Using commercial filament, the instrument costs about U.S. $25, which is less than half of all commercially available systems. However, the costs can be dropped further using recycled plastics on open source systems for over 99% savings. The results are discussed in the context of resource-constrained medical and scientific facilities.

Keywords: 3-D printing; additive manufacturing; biomedical equipment; biomedical engineering; centrifuge; design; distributed manufacturing; laboratory equipment; open hardware; open source; open source hardware; medical equipment; medical instrumentation; scientific instrumentation

### 1. Introduction

Adopting an open-source model of technological development enables equipment designers to quickly build upon one another’s work [1–3]. This democratization of design assists many individuals in effectively working together by making a range of contributions over time using open source tools [4–6]. Some of the most effective tools for encouraging widespread open hardware designs are themselves means of digital distributed manufacturing [7,8]. For example, the open source nature of the self-replicating rapid prototyper (RepRap) 3-D printer [9–11] has radically increased the accessibility of additive manufacturing (AM) while eviscerating the costs of rapid prototyping and product fabrication [12–15]. RepRaps and derivative commercial variants have obtained mechanical 3-D printed part strengths [16] and qualities of interest to the scientific community [17]. Many open source digitally fabricated devices are now widely used by the scientific community [18–20]. For example, 3-D printed parts are used in chemical mixing [2,20–24], optical and mechanical testing [24–26], water quality testing [27–30], and syringe pumping [31–34] (which

Instruments 2019, 3, 30 | 2 of 19

can be in turn used for more complicated systems such as fabricating microfluidics and metafluidics [35–37] or slot die deposition [38]). In addition to offering scientists the ability to customize their equipment and fully control their function, open source 3-D printable tools are much less expensive than equivalent or inferior commercial systems [18,39,40]. In general, these economic savings are greater for a high percentage of the components able to be 3-D printed [41]. A high return on investment (ROI) is realized for distributed manufacturing with commercial polymer 3-D printing filament based on downloaded substitution values [42,43]. In order to continue to “stand on the shoulders of giants” in open hardware [44], this paper describes the design of an open source completely 3-D printable centrifuge.
A centrifuge is a machine that holds rapidly rotating containers while applying centrifugal force to the fluids inside the containers to separate them based on different densities. Centrifuges are commonly required devices in medical diagnostics facilities because they are used for determining the concentration of pathogens and parasites in biological fluids, DNA preparation, and the extraction of plasma from the whole blood needed for immunoassays or hematocrit analysis. There are many commercial laboratory centrifuges and a number of open source variants, including the open analytical ultracentrifugation (AUC) [45], the laser cut OpenFuge [46], the Polyfuge [47], several variations of minicentrifuges [48–50], and one that uses a Dremel and 3-D printed chuck [51]. These open hardware tools do provide for those without access to more expensive proprietary tools [52], but they all depend on access to electricity. Unfortunately, an estimated 1.1 billion people (e.g., 14% of the global population) do not have access to electricity [53]. In addition, even many of those that do have access to electricity have unreliable power. For example, in Nigeria, power outages over extended times have forced a shift to expensive and polluting captive power generation in the majority of businesses [54]. To overcome this challenge of reliable electric power, several open source hand-powered centrifuges have been developed, including the paperfuge [55], a salad spinner centrifuge [56], and an eggbeater centrifuge [57]. All of these are functional, but they lack either large volume capabilities [55] or reliability. To overcome this, several companies have commercialized relatively robust hand-crank centrifuges, which cost U.S. $60–100 [58,59]. These costs can still be prohibitive, and as centrifugation is the first key step in most diagnostic assays [60], there is a need for a low-cost, portable, human-powered centrifuge that can be used by scientists and medical personnel, especially for diagnostics in resource-limited environments [60–63].
This study provides the designs for a low-cost 100% 3-D printed centrifuge apparatus, which can be fabricated on any low-cost RepRap-class fused filament fabrication (FFF)- or fused particle fabrication (FPF)-based 3-D printer. In addition, a validation procedure for quantifying the rotational speed is provided, which makes use of a smart phone or web camera. The design was fabricated and tested, and the results are discussed in the context of resource-constrained medical and scientific facilities.

### 2. Materials and Methods

2.1. Design

The design goal for this apparatus was to provide 1200 rotations per minute (rpm), with a handle rotational speed of the operator (N1) of 120 rpm (i.e., 2 rotations in 1 second). This centrifuge apparatus uses one set of spur gears and one set of bevel gears to achieve the desired gear ratio. Figure 1 shows the design of the gearing system.

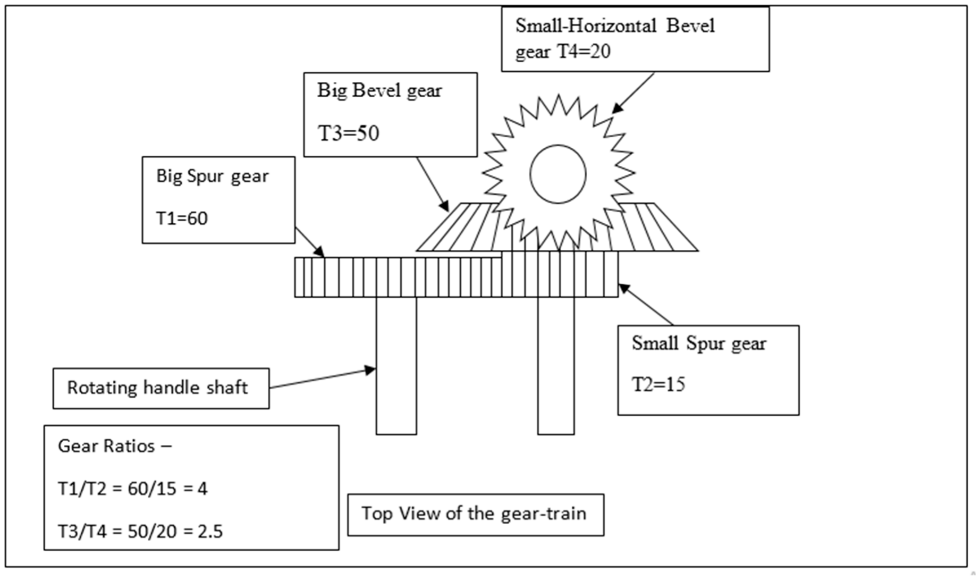
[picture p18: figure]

Figure 1. Schematic of gear design.

2.1.1. Gear Designing and Final Drive Calculations

Considering the rotational speed of the handle by the operator, N1 to be 120 rpm, the rotational speed for the 2nd spur gear, N2, is equal to 480rpm:

N2= N1T1/T2 | (1)

with the following teeth for the four gears:
- Teeth on 1st spur gear: T1 = 60;
- Teeth on 2nd spur gear: T2 = 15;
- Teeth on 1st bevel gear: T3 = 50;
- Teeth on 2nd bevel gear: T4 = 20.

Thus, N2 is 480 rpm, and as the 2nd spur gear and 1st bevel gear are coupled together,

N2 = N3 | (2)

Thus,

N4= N3T3/T4 = N2T3/T4 | (3)

Thus, N4 is 1200 rpm. Similarly, for an N1 of 150 rpm (i.e., 2.5 rotations of the handle per second), the final rotor speed is 1500 rpm.
Thus, for this apparatus, the number of test tube rotations (rt) is given by
rt = Crh | (4)

where the hand rotations per minute (rh) can be measured, and C is a constant of 10. With these parameters, it is also possible to calculate the relative centrifugal force (RCF), which is the amount of acceleration that is exerted on the sample in the apparatus. The RCF is dependent on the speed of the rotor and the distance of the matter in the test tubes from the center of the rotation. When the unit of rotation (N4) is in rpm, the RCF is given by

RCF = 1.118 × 10⁻⁶ × R [mm] × N42 [rpm] | (5)

where R is the radius of the rotor to the center of the test tubes used added to the test tube length (mm), and N4 is given by Equation (3). In the example shown here, with the radius of the rotor (50 mm) test tubes used and the length of the test tubes (100 mm) providing a total of 150 mm and an N4 of 1500 rpm, the RCF is 377.

2.1.2. Operation of Design
1. Rotating the handle rotates the bigger spur gear, which starts the motion. The two spur gears in contact have equal modules. The module is the ratio of the reference diameter of the gear to the number of teeth on the gear. The bigger spur gear has 60 teeth and a module of 2. Although a larger spur gear would yield a higher gear ratio, it would also increase the size of the casing and in turn the size of the whole apparatus. A spur gear with 60 teeth and a module of 1.5 modules was chosen, considering the need of the final required rotations of the rotor (N4). Meshed to the bigger spur gear is a smaller spur gear with an equal module. To mesh and rotate a set of any gears, it is necessary that both the gears should have the same profile and an equivalent module. This smaller spur gear is coupled to a larger bevel gear to eliminate the overhang and also another component required to hold the two together. The bigger bevel gear has 50 teeth and a module of 2. The bevel gear is used to transmit the motion in a perpendicular direction. A smaller bevel gear is then meshed with the large one to increase the rotations per minute of the test tubes.
2. High rotational speeds of 1200–2000 rpm are required to carry out typical medical tests. Thus, this gear train is designed in such a way that, with every two rotations per second, the rotor rotates at 1200 rpm. With every 2.5 rotations per second of the handle, the rotor rotates at 1500 rpm, and with 3 rotations per second, it can do 1800 rpm. The commercial equivalent products are capable of rotating at 1800 rpm, which is equal to the rotational capability of this 3-D printed centrifuge apparatus. The speeds can be easily increased if the number of teeth on either of the bevels or spurs or both bigger gears are increased and the source code in FreeCAD (computer-aided design 3-D modeling software, www.freecadweb.org) is made available for those that need this capability.
3. The dimensions of the handle are designed in such a way that it will not interfere with the rotation of the test tubes. The grip is designed to keep in mind the ergonomics of the human hand and its motion while rotating the handle. Enough grip is provided on the grip bar, which freely rotates around the centerpiece of the handle. The horizontal motion of grip is constrained by implementing a ball–socket joint at the end of the handle.
4. Test tubes are placed in the test rings, which are specifically designed for standard test tubes. However, there is a wide variety of test tubes that are available on the market. All of the part files in FreeCAD are made available and open source so that others can adapt the tube holders to meet other sizes of test tubes. The test rings that hold the test tubes are locked in the rotor by using rotor snaps. These snaps can easily withstand the high centrifugal forces acting on them, as they are tightly fitted in the rotor itself. The rotor diameter is 120 mm, which is enough to generate high centrifugal force, following Equation (4).
2.1.3. Bill of Materials

The bill of materials (BOM) is made up of all 3-D printed components, which are summarized in Table 1.

Table 1. Bill of materials for the 3-D printed open source centrifuge.

Component Quantity | Description | Image of Component
Part A | 1 | Front plate
Part B | 1 | Back plate
Part C | 1 | Bigger spur gear with locking pin
Part D | 1 | Smaller spur gear with large bevel gear

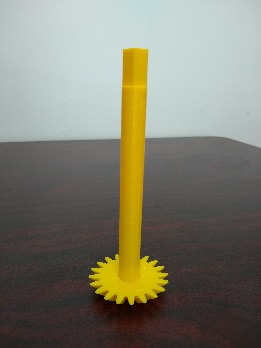
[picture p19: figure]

Part E | 1 | Smaller bevel gear
Part F | 1

Clamping ring for smaller bevel gear

(Part E)

Part G | 1 | Rotor for test tubes
Part H | 1 | Clamping for Part D

Part I | 4 | Rings for test tube

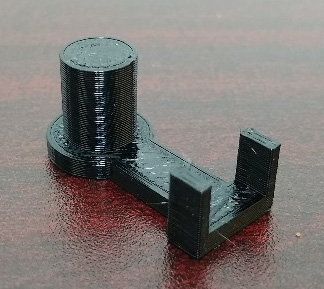
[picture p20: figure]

Part J | 8 | Snaps for rotor

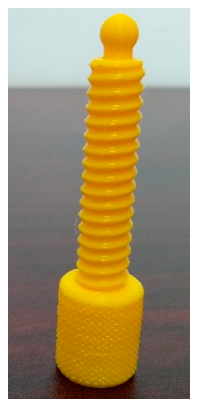
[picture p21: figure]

Part K | 2 | Bolts for clamping body
Part L | 2 | Base clips for the bolts
Part M | 1 | Smaller bevel gear holder

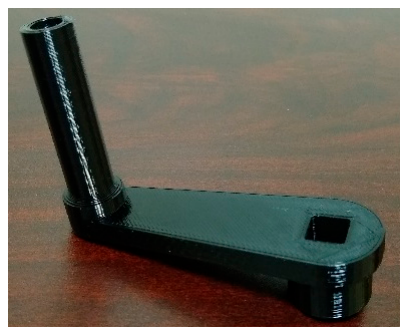
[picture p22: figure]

Part N | 1 | Handle
Part O | 1 | Grip for handle

Part P | 1 | Locking clip for handle
2.2. Fabrication

The components shown in Table 1 are available on the Open Science Framework [64] and are released under a GNU General Public License (GPL) 3.0 [65]. Parts K and L are borrowed from a creative commons-licensed C-clamp design [66]. All of the parts were 3-D printed with glycolmodified polyethylene terephthalate (PETG) IC3D filament of diameter 2.85 mm on a Lulzbot TAZ 6 (Aleph Objects, Loveland CO). The objects were sliced with Cura Lulzbot edition v.3.6.3 [67] using the standard settings summarized in Table 2.

Table 2. Slicer settings for each 3-D printed part.

Part Name Predefined Settings (Layer Height) Infill (%)
A | High speed (0.38 mm) | 40
B | High speed (0.38 mm) | 40
C | Standard (0.28 mm) | 65
D | Standard (0.28 mm) | 60
E | Standard (0.28 mm) | 60
F | High speed (0.38 mm) | 90
G | High speed (0.38 mm) | 40
H | High speed (0.38 mm) | 40
I | Standard (0.28 mm) | 50
J | Standard (0.28 mm) | 60
K | Standard (0.28 mm) | 50
L | High speed (0.38 mm) | 50
M | High speed (0.38 mm) | 65
N | High speed (0.38 mm) | 75
O | High speed (0.38 mm) | 45
P | High speed (0.38 mm) | 40
2.3. Assembly

All of the parts of the centrifuge apparatus are shown in Table 1, from Part A through Part O. The assembly of the open source centrifuge can be accomplished after the printed parts are prepared as follows. Part C is the big spur gear, whose end part (square-shaped) needs to be scraped with a knife or any sharp object before starting the assembly. Make sure to scrape a little material from the four edges on the square-shaped end of Part C to ensure a tight fit between Part C and the handle (Part N). This is an important step, as a tight fit will make rotating the handle easy and effective. All of the holes on Part A and Part B need to be scraped a little to ensure smooth rotations of the respective gears. This problem is created due to non-uniform printing by the FFF printer. The four sockets on Part A are to be scraped as well for perfect fitting of the ball joints of Part B. Carefully remove a small amount of material from all four sockets if the ball joints are not fitting inside the sockets. This operation may require some extra force. Part A and Part B are the two casings, which cover the gear train of the apparatus. Start assembling with Part B, as the gears are meshed inside this part (Figure 2).

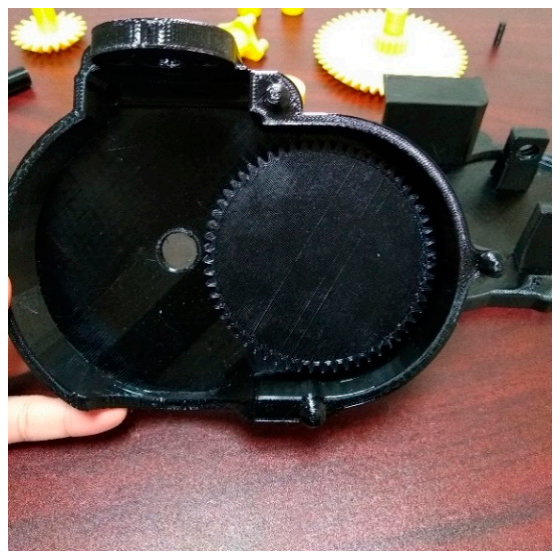
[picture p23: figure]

Figure 2. Assembling Parts B and C.

Part B has two holes of equal diameter where the gears are placed in order to carry out correct meshing. The right-hand side of Part B has a smaller diameter casing than the left-hand side does. Place Part C, which is the bigger spur gear, through the hole on the right-hand side (the smaller casing side, as seen in Figure 2). Lock the spur gear from the backside with the small connecting pin, which is included in Part C. This will help to constrain the horizontal movement of the spur gear and will keep the shaft in place while rotating.

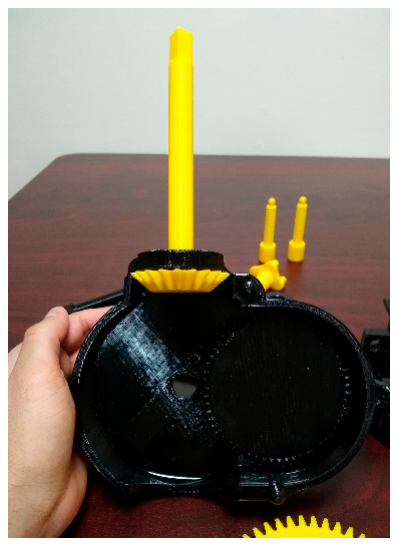
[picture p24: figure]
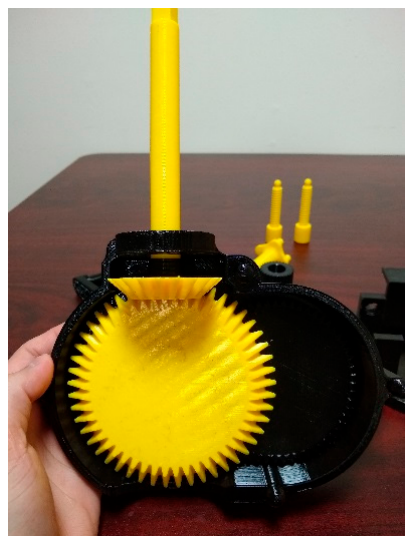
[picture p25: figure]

(a) (b)

Figure 3. (a) Inserting Part E into Part B and (b) inserting Part D.

Now insert Part E through the bigger circle situated on the top of Part B and hold it at the top (Figure 3a). Then insert Part D, which is the part with coupled gears, through the hole on the left side of Part B (Figure 3b).

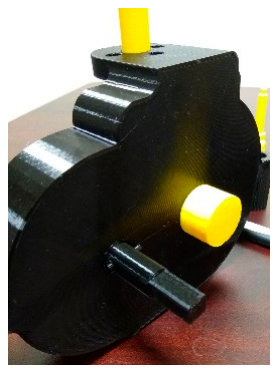
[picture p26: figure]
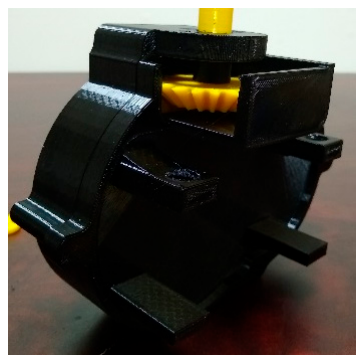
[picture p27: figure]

(a) (b)

Figure 4. (a) Attaching Part H and (b) Part E.

Attach part H from the backside of Part B in Part E’s hole, which will hold the couple gears in one place and stop them from swiveling abruptly while rotating (Figure 4a). Then place Part F, which is a small ring or clamp, to constrain the vertical motion of Part E (Figure 4b).

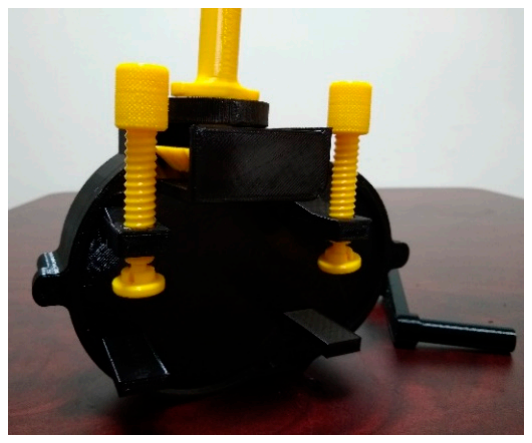
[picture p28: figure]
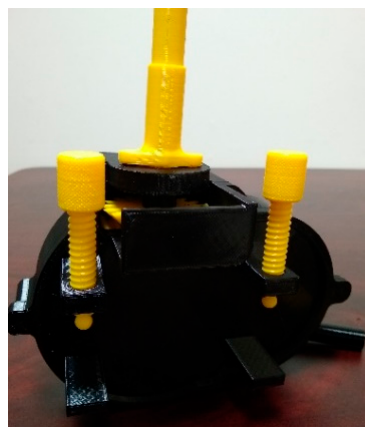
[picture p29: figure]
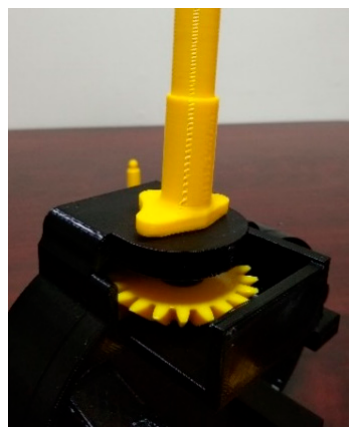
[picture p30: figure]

(a) | (b) | (c)

Figure 5. (a) Inserting part M and (b) assembling Parts K and (c) L.

Part A is the other half of the casing, which is used to cover the gear train and clamping. Part A and Part B are clamped to each other using four ball–socket joints. Insert Part M through Part E’s square end and fix it to the casing through the three given holes (Figure 5a). This will help the small bevel gear align perfectly in a vertical direction during rotations. Part K and Part L are used to clamp the whole centrifuge body to any even surface. Join both parts after Part K is passed through Part A’s internal threading. Join Part K and Part L using the ball–socket joint (Figure 5b).

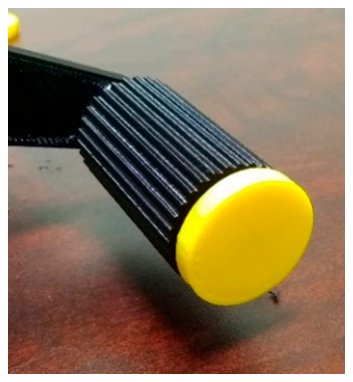
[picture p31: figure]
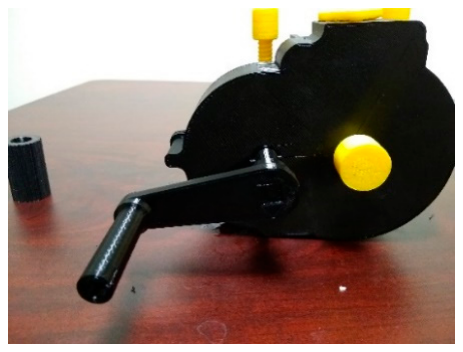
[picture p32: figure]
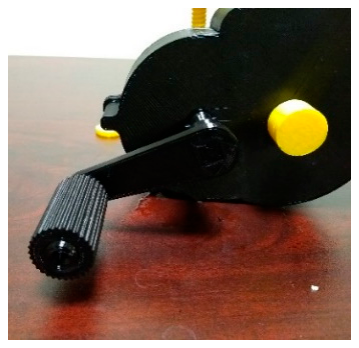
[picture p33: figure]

(a) | (b) | (c)

Figure 6. (a) Attaching handle N, and the (b) grip and (c) lock.

Part N, Part O, and Part P are the components of the handle. Lock Part N in the square end of Part C (Figure 6a). Make sure to scrape some material with the help of a knife or any sharp object from Part C’s square end to tightly fit Part C with Part N. If sufficient material is not scraped, then Part C will not fit with Part N, and if it is scraped more, then the handle will fit loosely, which will create a snapping problem while rotating the handle. Part O is the grip (Figure 6b), which is used to rotate the handle. Fix Part O and Part P with the ball–socket joint to fix the grip (Figure 6c).

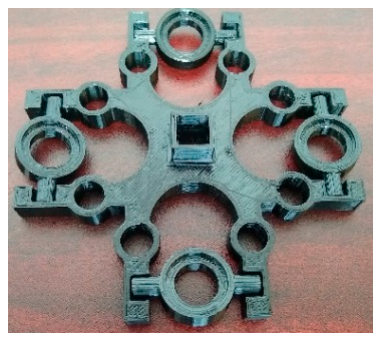
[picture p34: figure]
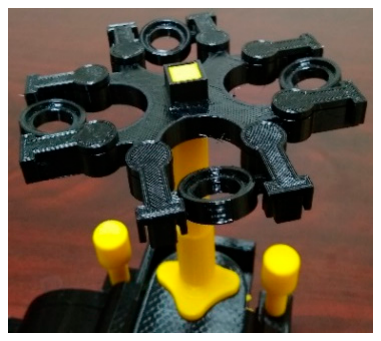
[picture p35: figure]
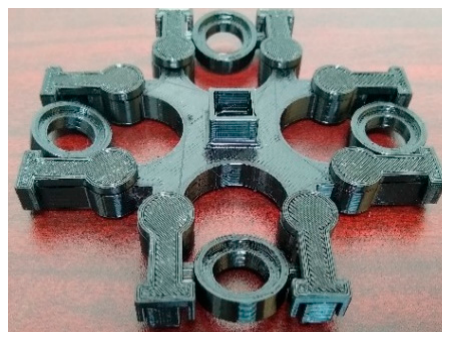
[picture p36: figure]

(a) | (b) | (c)

Figure 7. Assembling (a) Part G, (b) Part I, and (c) Part J.

Part G, Part I, and Part J are the parts of the rotor assembly (Figure 7). Part G is the rotor that will hold the rings (Part I) and the snaps (Part J). Place the rings in the rotor and clamp the rings by placing the snaps into the rotor. This will prevent the rings from falling during the motion due to high centrifugal force.

2.4. Operation

After completing the assembly, clamp the centrifuge apparatus on one side of a table (preferably a rectangular table and not a circular one). Place the test tubes in the test tube rings carefully. It is extremely important to balance the weight of the test tubes equally. Leaving out test tubes or heavily loading one will cause vibrations and will make the whole apparatus unstable while in operation. If only 3 of the test tubes are used for sample testing, make sure to fill the fourth test tube with water or a liquid that is of similar density to that of the sample. This will ensure an equal distribution of weight. Crank the handle, which is equipped with a grip.

2.5. Validation

As the working part of the centrifuge rotates at a speed of up to 2000 rpm, it may be difficult to track its motion, since the majority of regular web cameras operate at a frequency of 25–30 Hz. Thus, as the whole system represents a mechanical transmission with the fixed gear ratio, an indirect method was chosen to calculate the angular velocity of the tubes based on the speed of rotation of the centrifuge handle (Figure 8).
A Python-based software was developed to automatically measure the rotational speed of the centrifuge. The OpenCV library [68] was used for segmentation and tracking a visual marker located on the centrifuge handle, and the PyQt library [69] was used for creating an open source guided graphical user interface (GUI) application (Figure 9) [70].

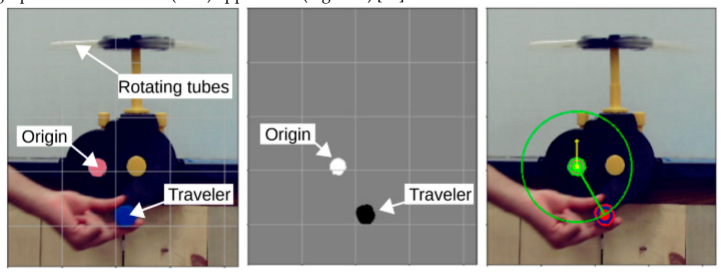
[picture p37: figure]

(a) | (b) | (c)

Figure 8. Image-based markers segmentation. (a) Cropped frame of the centrifuge with the visual markers; (b) masked image; (c) calculated handle orientation.

The developed application allows users to crop an arbitrary region of interest of the captured camera frame and set red, green and blue (RGB) thresholds for tracking the visual markers of any distinctive colors. It counts the number of centrifuge handle revolutions and calculates the angular velocity of the tubes. With the given information about the tube length, the program also computes its relative centrifugal force. In the case of normal manual rotation, the central marker will be periodically covered by the hand/arm of the user, so it is possible to set the x and y coordinates of the origin point in the program code.

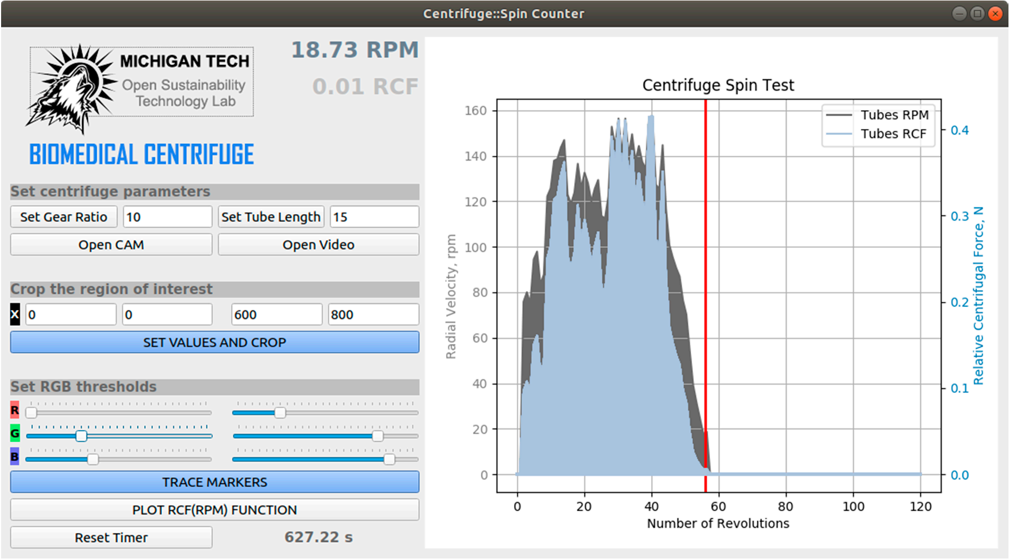
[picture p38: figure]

Figure 9. A screenshot of the open source biomedical centrifuge interface for camera-based rpm and relative centrifugal force calculations.

The main computer vision algorithm is provided below. The rpm and RCF calculations are based on tracking the coordinates of the traveler marker located on the centrifuge handle. By applying the specified color thresholds and morphological operations of “opening” and “closing” to a cropped camera frame, the user can mask the marker as a single separated color region. To find the coordinates of its centroid, the method of moments is employed, which allows the centrifuge handle orientation relative to the center of rotation to be calculated. To do this, RPM, the rotational velocity of the tubes in rpm, is given by

RPM =G⋅

60
Δt | (6)

where G is the gear ratio and Δt is the time interval for a single revolution in seconds. The RCF is given by
RCF = 1.118 ⋅ 10 ⋅ D ⋅ RPM
| (7)

where D is the length of the test tube with the radius of the centrifuge rotor in mm. A series of eight experiments for various rotational speeds for an RCF(rpm) plot were performed to compare the theory to experiments. Such a validation experiment is recommended for those building their own centrifuge before deployment. Depending on the critical nature of the application of the open source centrifuge, users may wish to record and run the validation for every experiment or simply keep track of the approximate number of rotations and rotations/minute of the handle to obtain an approximate RCF/rpm.
As can be seen in Figure 9, the user can set the RGB thresholds and crop the region of interest in the video. Users can also set the tube length and gear ratio to calculate the rpm and RCF. The RCF and rotational velocity are plotted in real time. The pseudo-code is given as follows:

Computing Angular Velocity and Relative Centrifugal Force
Input: an image frame from a camera or a video sequence.
Output: rpm and RCF values for the test tubes.

while a camera is open or a video is reading do:
get a single frame as an RGB image;

crop the region of interest of the image frame;
apply linear filtering to blur the cropped region;
mask the color marker using RGB thresholds;
apply operations of opening and closing to remove noise after RGB masking; find the contours of the masked area.

if the traveler marker is detected do:
find the centroid location of the color marker applying the method of moments; calculate the radius of rotation and the angle of the centrifuge arm.

if the angle is in a specified zero range do:
increase the number of revolutions by one;
update timer and compute the time period for one revolution; calculate the tubes’ rpm;
calculate the tubes’ RCF.
end if
end if
end while
2.6. Economic Analysis

In order to determine the costs of the apparatus, the entire device was massed on a digital scale +/−0.01 kg. The total cost (Tc) of the apparatus can be determined by
Tc = mCe + mCp | (8)

where m is the mass of all the 3-D printed parts (e.g., the whole apparatus); Ce is the cost of the electricity per kg to print; and Cp is the cost of plastic per kg. The electricity to operate the Lulzbot Taz 6 is about 9.11 kWh per kg, as measured by a multimeter +/- 0.01 kWh. The average cost of commercial electricity in the U.S. is $0.1029/kWh [71]. This value was used, assuming that the device was fabricated at a university or government laboratory, which would be considered a midrange value between those fabricating it using residential electricity rates (higher) and distributed solar photovoltaic electricity (lower). The cost of an IC3D filament from Lulzbot was U.S. $45/kg [72].

### 3. Results

All of the parts of the open source centrifuge can be printed on a standard RepRap-class FFFbased 3-D printer. Here, all of the parts were printed on a Lulzbot Taz 6 using standard print settings in PETG. Part A and Part B are the longest prints, and take more than 8 hours to complete each. All of the gears are printed with more than 60% fill, and thus they have printing times of more than three hours. The total printing time for all of the parts is about 35 h. The printing time can be reduced if the “high speed” (0.28 mm z height) predefined setting is used with a reduction in the infill percentage up to a certain level. In addition, a nozzle with a larger orifice would also speed up printing.
The open source centrifuge takes about 30 min to assemble after printing all of the parts if all the instructions in Section 2.3 are carefully followed. The open source centrifuge is shown fully assembled in a pre-spin state clamped to a desk in Figure 10. The complete system with filled test tubes is shown during rotation in Figure 11a, and a screen capture of a centrifuge cam used for the GUI is shown in Figure 11b. Note the blue tape on the handle end to enable easy computer vision analysis. The same functionality can be obtained using a different colored 3-D print for Part P, coloring it with a marker, or using a sticker. To see the device in operation, see Supplementary Materials, Video S1: MOST_CENTRIFUGE_VIDEO.avi.

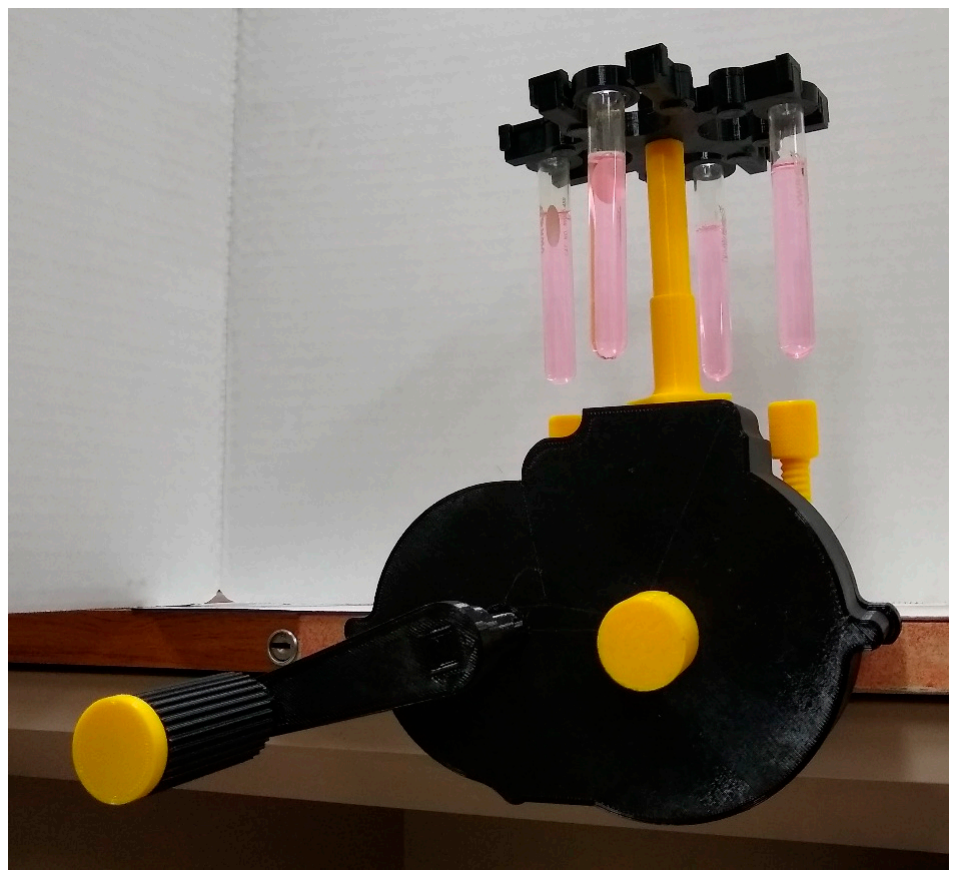
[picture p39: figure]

Figure 10. Fully assembled open source centrifuge in a pre-spin state.

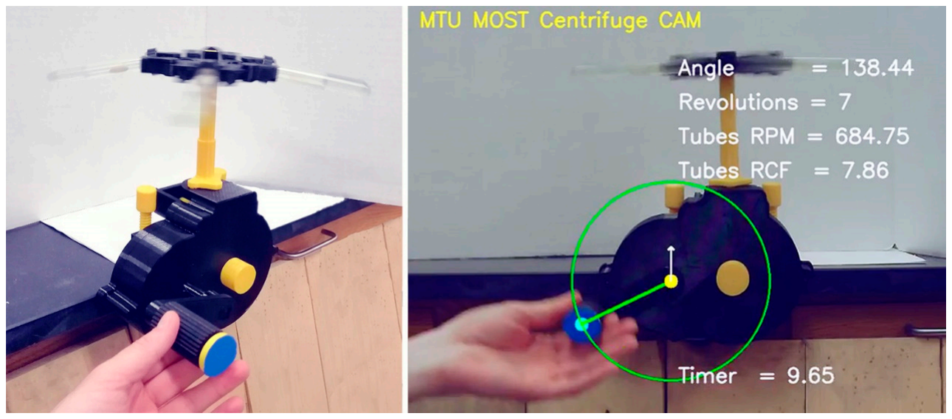
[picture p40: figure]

(a) (b)

Figure 11. (a) Complete system with filled test tubes during rotation and (b) a screen capture of a centrifuge cam used for the graphical user interface (GUI). Tracking of the handle marker, time, angle, number of revolutions, rpm, and RCF are all shown in real time.

During validation experiments with filled test tubes, the RCF(rpm) function was obtained for a wide range of rotational velocities and compared to theoretical Equation (5) for the test tubes with a length of 100 mm and a total radius of rotation D = 150 mm (Figure 12). The goal of the validation was to confirm that there was no time delay in the computer program between calculating the rotational velocity and the relative centrifugal force. As can be seen in Figure 12, the apparatus performed as expected from a start at stationary to over 1750 rpm. This verified the real-time plot (Figure 9), which displayed a proper RCF/rpm ratio over time and over the full range of rotational velocities. In locations without access to a camera, smart phone, and computer during use, crude estimates could be determined by hand calculations of the same equations using a stopwatch and hand rotation counting to determine the RCF.

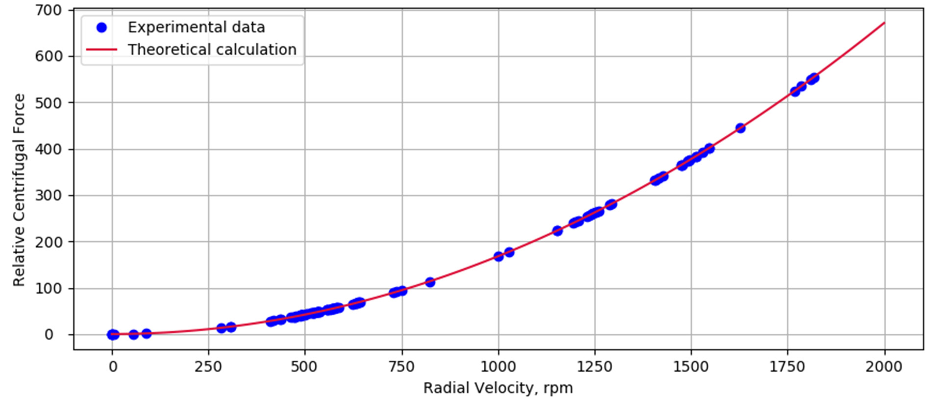
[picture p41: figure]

Figure 12. Relative centrifugal force as a function of the rotational velocity of the centrifuge test tubes with a length of 100 mm and a total radius of rotation D = 150 mm (Equation (7)).

### 4. Discussion

This study successfully described, tested, and validated a completely open source centrifuge, which can be fabricated using only open source tools, validated with a laptop computer with a webcam using only free and open source software, and operated anywhere in the world with no electricity inputs. In addition, this device can be fabricated for far less than commercial proprietary tools. The total mass of the apparatus is 0.550 kg, which results in about U.S. $0.50 in electricity costs and $24.75 in commercial costs of filament, for a total cost of U.S. $25.26. Parts M and N both require printing with support and the use of 2 and 11 grams, respectively. This adds about 60 U.S. cents to the total cost (U.S. $25.88). This compares to commercial systems, which cost U.S. $60–100 [59,60] and do not have a means of easy field validation without the use of the open source GUI disclosed here. Thus, a considerable savings of a 57–75% decrease in cost can be achieved with this device. However, as this device is primarily developed for applications in resource-constrained settings, further cost reductions are needed.
The economics of using commercial 3-D printing filament are somewhat attractive: However, they can be improved by using filament fabricated with a recyclebot [73–75] from recycled waste polymers. Former 3-D printed polymers can be recycled with acceptable mechanical strengths for about five cycles [76,77]. Thermopolymers, which have already been demonstrated with recyclebot processing, include polylactic acid (PLA) [75–79], PET and PETG [80–82], high-density polyethylene (HDPE) [74,82–87], acrylonitrile butadiene styrene (ABS) [82,86–90], polystyrene (PS) [82], polypropylene (PP) [82], elastomers [91], as well as polypropylene blends [92] and composites such as waste wood biopolymers [93] and carbon fiber-reinforced plastics [94]). Modern recyclebots can produce filament from waste plastic for electricity costs between 2.4 [90] and 3.6 [75] cents/kg. As the design here was massed at 0.550 kg, it would cost between 1.3 and 2 cents in recycled filament and about 91 cents to print, which results in a total cost of about U.S. $0.92–$0.93. This provides savings of 98%–99% compared to commercial offerings. It should be pointed out here that these costs do not include any labor costs for either the collecting, sorting, or processing (shredding) of the waste plastic to feedstock for the recyclebot. Commercial recycled plastic granules are available from U.S. $1.00– 3.00/kg. Purchasing relatively expensive commercial recycled plastic would still result in a centrifuge cost of only a dollar or two. However, there are two ways these costs can be even further reduced from the sub-dollar costs associated with distributed recycling with a recyclebot system. The first involves using a previously acquired solar photovoltaic-powered recyclebot [78,87,89] and a solar-powered 3-D printer [87,89,95–97]. The electricity costs are then avoided, dropping the marginal costs of materials and energy near to zero, although the capital cost would need to be amortized by printing many valuable products or be given as a donation. In addition, direct fused particle fabrication (FPF)

or fused granular fabrication (FGF) can be used to recycle a wide range of materials, including PET, PP, ABS, and PLA [98]. Directly printing (material extrusion) shredded waste plastic and avoiding filament manufacturing takes the cost of the materials and processing of the open source centrifuge down under U.S. $0.50. The commercial open source FPF/FGF systems have high capital costs, although they can fabricate generally large, valuable products that provide users with a high return on investment if they are used frequently [99]. Future work is needed to make a desktop scale particle material extrusion 3-D printer and apply it to manufacturing of this device.
This study indicates several areas of future work. First, more research is needed to make smallscale FPF/FGF 3-D printers to fabricate waste plastic into open source centrifuges for resource-constrained areas. Such systems would ideally be solar photovoltaic-powered. Future work could also look at the potential for a 3-D printable waste plastic shredder, again ideally solar or manual powered, that could be used to complete the entire tool chain from waste to finished scientific instrument. It should be noted that in the cost calculations above, labor costs were not included. Future work can address the labor costs in a range of contexts: However, a past analysis of open hardware for science by Trivedi et al. [23] has shown that zero labor costs are relevant to several scientific instrument situations where (i) there is no opportunity cost to using existing salaried employees (e.g., lab managers, research assistants, teaching assistants, or other positions that are paid as a fixed cost and for which there is no opportunity cost of work on the fabrication of the device); (ii) fabrication of the instruments is used as a learning aid [100,101]; or (iii) the labor is provided by unpaid interns or volunteers (e.g., undergraduate students volunteering for research experience). In general, in resource-constrained settings, as well as in most academic institutions, these conditions can be met. For those settings where this is not the case, tasks to order and deploy a commercial product should be compared to the relatively low time investment of printing (only set-up and takeoff is necessary, as the 3-D printers can be left unattended) and assembling the open source centrifuge.

### 5. Conclusions

This paper provides complete open source plans, including a BOM, instructions for fabrication and operation, and open source software for a hand-powered centrifuge. This study successfully described, tested, and validated this completely open source centrifuge, which can be fabricated using only open source tools (e.g., a RepRap-class 3-D printer). Further, the validation itself used only open source and readily available tools of a computer with a webcam. The instrument can be operated anywhere in the world with no electricity inputs, obtaining a radial velocity of over 1750 rpm and over 50 N of relative centrifugal force. Using commercial filament, the instrument costs about U.S. $25, which is less than half of all commercially available systems. However, the costs can be dropped further using recycled plastics in open source systems for over 99% savings.

Supplementary Materials: The following are available online at: www.mdpi.com/2410-390X/3/2/30/s1. Video S1: MOST_CENTRIFUGE_VIDEO.avi.

Author Contributions: Conceptualization, Joshua M. Pearce; data curation, Aliaksei L. Petsiuk; formal analysis, Salil S. Sule, Aliaksei L. Petsiuk, and Joshua M. Pearce; funding acquisition, Joshua M. Pearce; investigation, Salil
S. Sule and Aliaksei L. Petsiuk; methodology, Salil S. Sule, Aliaksei L. Petsiuk, and Joshua M. Pearce; resources, Joshua M. Pearce; software, Aliaksei L. Petsiuk; supervision, Joshua M. Pearce; validation, Aliaksei L. Petsiuk; visualization, Salil S. Sule and Aliaksei L. Petsiuk; writing—original draft, Salil S. Sule, Aliaksei L. Petsiuk, and Joshua M. Pearce; writing—review and editing, Salil S. Sule, Aliaksei L. Petsiuk, and Joshua M. Pearce.

Funding: This research was funded by Aleph Objects and the Richard Witte Endowment.

Acknowledgments: The authors would like to thank Shaunak P. Mhatre for technical assistance.

Conflicts of Interest: The authors declare no conflicts of interest. The funders had no role in the design of the study; in the collection, analyses, or interpretation of data; in the writing of the manuscript; or in the decision to publish the results.

References

1. Gibb, A. Building Open Source Hardware: DIY Manufacturing for Hackers and Makers; Pearson Education, New York, NY, USA, 2014.
2. Da Costa, E.T.; Mora, M.F.; Willis, P.A.; Lago, C.L. do; Jiao, H.; Garcia, C.D. Getting started with openhardware: Development and control of microfluidic devices. Electrophoresis 2014, 35, 2370–2377.
3. Ackerman, J.R. Toward open source hardware. U. Dayton L. Rev. 2008, 34, 183–222.
4. Powell, A. Democratizing production through open source knowledge: From open software to open hardware. Media Cult. Soc. 2012, 34, 691–708.
5. Von Hippel, E. Democratizing innovation: The evolving phenomenon of user innovation. JfB 2005, 55, 63– 78.
6. Blikstein, P. Digital fabrication and “making” in education: The democratization of invention. FabLabs Mach. Mak. Invent. 2013, 4, 1–21.
7. Gershenfeld, N. How to Make Almost Anything: The Digital Fabrication Revolution. Available online: http://cba.mit.edu/docs/papers/12.09.FA.pdf (accessed on 16 May 2019).
8. Wittbrodt, B.; Laureto, J.; Tymrak, B.; Pearce, J. Distributed manufacturing with 3-d printing: A case study of recreational vehicle solar photovoltaic mounting systems. J. Frugal Innov. 2015, 1, 1–7.
9. Sells, E.; Bailard, S.; Smith, Z.; Bowyer, A.; Olliver, V. RepRap: The Replicating Rapid Prototyper-Maximizing Customizability by Breeding the Means of Production. In Proceedings of the World Conference on Mass Customization and Personalization, Cambridge, MA, USA, 7–10 October 2007.
10. Jones, R.; Haufe, P.; Sells, E.; Iravani, P.; Olliver, V.; Palmer, C.; Bowyer, A. RepRap-the replicating rapid prototyper. Robotica 2011, 29, 177–191.
11. Bowyer, A. 3D Printing and humanity’s first imperfect replicator. 3D Print. Addit. Manuf. 2014, 1, 4–5.
12. Kietzmann, J.; Pitt, L.; Berthon, P. Disruptions, decisions, and destinations: Enter the age of 3-D printing and additive manufacturing. Bus. Horiz. 2015, 58, 209–215.
13. Lipson, H.; Kurman, M. Fabricated: The New World of 3D Printing; John Wiley & Sons: Indianapolis, IN, USA, 2013.
14. Gwamuri, J.; Wittbrodt, B.; Anzalone, N.; Pearce, J. Reversing the trend of large scale and centralization in manufacturing: The case of distributed manufacturing of customizable 3-d-printable self-adjustable glasses. Chall. Sustain. 2014, 2, 30–40.
15. Attaran, M. The rise of 3-D printing: The advantages of additive manufacturing over traditional manufacturing. Bus. Horiz. 2017, 60, 677–688.
16. Tanikella, N.G.; Wittbrodt, B.; Pearce, J.M. Tensile strength of commercial polymer materials for fused filament fabrication 3D printing. Addit. Manuf. 2017, 15, 40–47.
17. Pearce, J.M. Building research equipment with free, open-source hardware. Science 2012, 337, 1303–1304.
18. Pearce, J. Open-Source Lab: How to Build Your Own Hardware and Reduce Research Costs; Elsevier: New York, NY, USA, 2013.
19. Baden, T.; Chagas, A.M.; Gage, G.; Marzullo, T.; Prieto-Godino, L.L.; Euler, T. Open labware: 3-D printing your own lab equipment. PLoS Biol. 2015, 13, e1002086, doi:10.1371/journal.pbio.1002086.
20. Coakley, M.; Hurt, D.E. 3D Printing in the laboratory: Maximize time and funds with customized and open-source labware. J. Lab. Autom. 2016, 21, 489–495.
21. Zhang, C.; Wijnen, B.; Pearce, J.M. Open-Source 3-D platform for low-cost scientific instrument ecosystem.
J. Lab. Autom. 2016, 21, 517–525.
22. Dhankani, K.C.; Pearce, J.M. Open source laboratory sample rotator mixer and shaker. HardwareX 2017, 1, 1–12.
23. Trivedi, D.K.; Pearce, J.M. Open Source 3-D Printed Nutating Mixer. Appl. Sci. 2017, 7, 942.
24. Zhang, C.; Anzalone, N.C.; Faria, R.P.; Pearce, J.M. Open-Source 3D-Printable Optics Equipment. PLoS ONE 2013, 8, e59840.
25. Winters, B.J.; Shepler, D. 3D printable optomechanical cage system with enclosure. HardwareX 2018, 3, 62– 81.
26. Agcayazi, T.; Foster, M.; Kausche, H.; Gordon, M.; Bozkurt, A. Multi-axis stress sensor characterization and testing platform. HardwareX 2019, 5, e00048.
27. Anzalone, G.C.; Glover, A.G.; Pearce, J.M. Open-Source Colorimeter. Sensors 2013, 13, 5338–5346.
28. Kelley, C.D.; Krolick, A.; Brunner, L.; Burklund, A.; Kahn, D.; Ball, W.P.; Weber-Shirk, M. An Affordable Open-Source Turbidimeter. Sensors 2014, 14, 7142–7155.

29. Wijnen, B.; Anzalone, G.C.; Pearce, J.M. Open-source mobile water quality testing platform. J. Water Sanit. Hyg. Dev. 2014, 4, 532–537.
30. Wittbrodt, B.T.; Squires, D.A.; Walbeck, J.; Campbell, E.; Campbell, W.H.; Pearce, J.M. Open-Source Photometric System for Enzymatic Nitrate Quantification. PLoS ONE 2015, 10, e0134989.
31. Wijnen, B.; Hunt, E.J.; Anzalone, G.C.; Pearce, J.M. Open-Source Syringe Pump Library. PLoS ONE 2014, 9, e107216.
32. Bravo-Martinez, J. Open source 3D-printed 1000 μL micropump. HardwareX 2018, 3, 110–116.
33. Pusch, K.; Hinton, T.J.; Feinberg, A.W. Large volume syringe pump extruder for desktop 3D printers. HardwareX 2018, 3, 49–61.
34. Garcia, V.E.; Liu, J.; DeRisi, J.L. Low-cost touchscreen driven programmable dual syringe pump for life science applications. HardwareX 2018, 4, e00027.
35. Pearce, J.M.; Anzalone, N.C.; Heldt, C.L. Open-Source Wax RepRap 3-D Printer for Rapid Prototyping Paper-Based Microfluidics. J. Lab. Autom. 2016, 21, 510–516.
36. Kong, D.S.; Thorsen, T.A.; Babb, J.; Wick, S.T.; Gam, J.J.; Weiss, R.; Carr, P.A. Open-source, communitydriven microfluidics with Metafluidics. Nat. Biotechnol. 2017, 35, 523–529.
37. Niezen, G.; Eslambolchilar, P.; Thimbleby, H. Open-source hardware for medical devices. BMJ Innov. 2016, 2, 78–83.
38. Beeker, L.Y.; Pringle, A.M.; Pearce, J.M. Open-source parametric 3-D printed slot die system for thin film semiconductor processing. Addit. Manuf. 2018, 20, 90–100.
39. Pearce, J.M. Laboratory equipment: Cut costs with open-source hardware. Nature 2014, 505, 618.
40. Pearce, J.M., Impacts of Open Source Hardware in Science and Engineering. Bridge 2017, 47, 24–31.
41. Hietanen, I.; Heikkinen, I.T.S.; Savin, H.; Pearce, J.M. Approaches to open source 3-D printable probe positioners and micromanipulators for probe stations. HardwareX 2018, 4, e00042.
42. Pearce, J. Quantifying the Value of Open Source Hardware Development. Mod. Econ. 2015, 6, 1–11.
43. Pearce, J.M. Return on investment for open source scientific hardware development. Sci. Public Policy 2016, 43, 192–195.
44. Dryden, M.D.M.; Fobel, R.; Fobel, C.; Wheeler, A.R. Upon the Shoulders of Giants: Open-Source Hardware and Software in Analytical Chemistry. Anal. Chem. 2017, 89, 4330–4338.
45. Cölfen, H.; Laue, T.M.; Wohlleben, W.; Schilling, K.; Karabudak, E.; Langhorst, B.W.; Brookes, E.; Dubbs, B.; Zollars, D.; Rocco, M.; et al. The Open AUC Project. Eur. Biophys. J. 2010, 39, 347–359.
46. CopabX, OpenFuge. Available online: https://www.instructables.com/id/OpenFuge/(accessed on 28 March 2019).
47. Polyfuge: | A | DIY | Open-Source | Microcentrifuge | for | Everyone. | Available | online:
https://www.kickstarter.com/projects/1733191226/polyfuge-a-diy-open-source-microcentrifuge-for-eve (accessed on 28 March 2019).
48. Warejoncas, Z.; Stewart, C.; Giannini, J. An Inexpensive, Open-Source Mini-Centrifuge. AMBT 2018, 80, 451–456.
49. Progress | TH | Follow | 3D | Printed | DIYbio | Mini-Centrifuge. | Available | online:
https://www.instructables.com/id/3D-Printed-DIYbio-Mini-Centrifuge/ (accessed on 28 March 2019).
50. Thingiverse. | El-Cheapo | Table | Top | Mini | Fuge | by | Tiny | Tim. | Available | online:
https://www.thingiverse.com/thing:33818 (accessed on 28 March 2019).
51. Garvey, C. Thingiverse.com DremelFuge—A One-Piece Centrifuge for Rotary Tools by Cathal Garvey. Available online: https://www.thingiverse.com/thing:1483 (accessed on 28 March 2019).
52. Chagas, A.M. Haves and have nots must find a better way: The case for open scientific hardware. PLoS Biol. 2018, 16, e3000014.
53. International Energy Agency. Energy Access Outlook. Available online: https://www.iea.org/access2017/(accessed on 28 March 2019).
54. Edomah, N. Governing sustainable industrial energy use: Energy transitions in Nigeria’s manufacturing sector. J. Clean. Prod. 2019, 210, 620–629.
55. Bhamla, M.S.; Benson, B.; Chai, C.; Katsikis, G.; Johri, A.; Prakash, M. Hand-powered ultralow-cost paper centrifuge. Nat. Biomed. Eng. 2017, 1, 0009.
56. Brown, J.; Theis, L.; Kerr, L.; Zakhidova, N.; O’Connor, K.; Uthman, M.; Oden, Z.M.; Richards-Kortum, R. A hand-powered, portable, low-cost centrifuge for diagnosing anemia in low-resource settings. Am. J. Trop. Med. Hyg. 2011, 85, 327–332.

57. Wong, A.P.; Gupta, M.; Shevkoplyas, S.S.; Whitesides, G.M. Egg beater as centrifuge: Isolating human blood plasma from whole blood in resource-poor settings. Lab. Chip. 2008, 8, 2032–2037.
58. Hand-Driven Centrifuge. Southern Labware. Available online: https://www.southernlabware.com/hand-driven-centrifuge.html (accessed on 28 March 2019).
59. Hand-Driven Centrifuge. Carolina.com. Available online: https://www.carolina.com/catalog/detail.jsp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 (accessed on 28 March 2019).
60. Mabey, D.; Peeling, R.W.; Ustianowski, A.; Perkins, M.D. Tropical infectious diseases: Diagnostics for the developing world. Nat. Rev. Microbiol. 2004, 2, 231–240.
61. Urdea, M.; Penny, L.A.; Olmsted, S.S.; Giovanni, M.Y.; Kaspar, P.; Shepherd, A.; Wilson, P.; Dahl, C.A.; Buchsbaum, S.; Moeller, G.; et al. Requirements for high impact diagnostics in the developing world. Nature 2006, 444, 73–79.
62. Dineva, M.A.; Mahilum-Tapay, L.; Lee, H. Sample preparation: A challenge in the development of pointof-care nucleic acid-based assays for resource-limited settings. Analyst 2007, 132, 1193–1199.
63. Mariella, R. Sample preparation: The weak link in microfluidics-based biodetection. Biomed. Microdev. 2008, 10, 777.
64. OSF. Available online: https://osf.io/besmf/ (accessed on 16 April 2019).
65. GNU General Public License Version 3. Available online: https://www.gnu.org/licenses/gpl-3.0.en.html (accessed on 29 March 2019).
66. Joe, J. Fully Printable C-Clamp Licensed Under Creative Commons—Attribution License. Available online: https://www.thingiverse.com/thing:1673030 (accessed on 29 March 2019).
67. Cura LulzBot Edition. Available online: https://www.lulzbot.com/cura (accessed on 2 April 2019).
68. OpenCV (Open Source Computer Vision Library). Available online: https://opencv.org/ (accessed on 16 April 2019).
69. PyQt. Available online: https://wiki.python.org/moin/PyQt (accessed on 16 April 2019).
70. MOST_Centrifuge_GUI. Available online: https://github.com/apetsiuk/MOST_Centrifuge_GUI (accessed on 16 April 2019).
71. EIA. | Electric | Power | Monthly. | Available | online:
https://www.eia.gov/electricity/monthly/epm_table_grapher.php?t=epmt_5_6_a (accessed on 16 April 2019).
72. PETg 3D Printer Filament. IC3D Filament. Available online: https://www.lulzbot.com/store/filament/ic3dpetg (accessed on 2 April 2019).
73. Recyclebot. Appropedia. Available online: http://www.appropedia.org/Recyclebot (accessed on 2 April 2019).
74. Baechler, C.; DeVuono, M.; Pearce, J.M. Distributed recycling of waste polymer into RepRap feedstock. Rapid Prototyp. J. 2013, 19, 118–125, doi:10.1108/13552541311302978.
75. Woern, A.L.; McCaslin, J.R.; Pringle, A.M.; Pearce, J.M. RepRapable Recyclebot: Open source 3-D printable extruder for converting plastic to 3-D printing filament. HardwareX 2018, 4, e00026, doi:10.1016/j.ohx.2018.e00026.
76. Cruz Sanchez, F.; Lanza, S.; Boudaoud, H.; Hoppe, S.; Camargo, M. Polymer recycling and additive manufacturing in an open source context: Optimization of processes and methods. In Proceedings of the 2015 Annual International Solid Freeform Fabrication Symposium-An Additive Manufacturing Conference, Austin, TX, USA, 12–14 August 2015; pp. 10–12.
77. Cruz Sanchez, F.A.C.; Boudaoud, H.; Hoppe, S.; Camargo, M. Polymer recycling in an open-source additive manufacturing context: Mechanical issues. Addit. Manuf. 2017, 17, 87–105.
78. Zhong, S.; Rakhe, P.; Pearce, J.M. Energy Payback Time of a Solar Photovoltaic Powered Waste Plastic Recyclebot System. Recycling 2017, 2, 10.
79. Anderson, I. Mechanical properties of specimens 3d printed with virgin and recycled polylactic acid. 3D Print. Addit. Manuf. 2017, 4, 110–115, doi:10.1089/3dp.2016.0054.
80. Woern, A.L.; Pearce, J.M. 3-D Printable polymer pelletizer chopper for fused granular fabrication-based additive manufacturing. Inventions 2018, 3, 78.
81. Zander, N.E.; Gillan, M.; Lambeth, R.H. Recycled polyethylene terephthalate as a new FFF feedstock material. Addit. Manuf. 2018, 21, 174–182.

82. Pepi, M.; Zander, N.; Gillan, M. Towards Expeditionary Battlefield Manufacturing Using Recycled, Reclaimed, and Scrap Materials. JOM 2018, 70, 2359–2364.
83. Chong, S.; Pan, G.-T.; Khalid, M.; Yang, T.C.-K.; Hung, S.-T.; Huang, C.-M. Physical Characterization and Pre-assessment of Recycled High-Density Polyethylene as 3D Printing Material. J. Polym. Environ. 2017, 25, 136–145, doi:10.1007/s10924-016-0793-4.
84. Kreiger, M.; Anzalone, G.C.; Mulder, M.L.; Glover, A.; Pearce, J.M. Distributed recycling of post-consumer plastic waste in rural areas. MRS Online Proc. 2013, 1492, 91–96.
85. Kreiger, M.A.; Mulder, M.L.; Glover, A.G.; Pearce, J.M. Life cycle analysis of distributed recycling of post-consumer high density polyethylene for 3-D printing filament. J. Clean. Prod. 2014, 70, 90–96.
86. Mohammed, M.I.; Mohan, M.; Das, A.; Johnson, M.D.; Badwal, P.S.; McLean, D.; Gibson, I. A low carbon footprint approach to the reconstitution of plastics into 3D-printer filament for enhanced waste reduction. KnE Eng. 2017, 2, 234–241.
87. Mohammed, M.I.; Wilson, D.; Gomez-Kervin, E.; Rosson, L.; Long, J. EcoPrinting: Investigation of Solar Powered Plastic Recycling and Additive Manufacturing for Enhanced Waste Management and Sustainable Manufacturing. In Proceedings of the 2018 IEEE Conference on Technologies for Sustainability (SusTech); Long Beach, CA, USA, 9–12 November 2018; pp. 1–6.
88. Mohammed, M.I.; Das, A.; Gomez-Kervin, E.; Wilson, D.; Gibson, I. EcoPrinting: Investigating the use of 100% recycled Acrylonitrile Butadiene Styrene (ABS) for Additive Manufacturing. Solid Freeform Fabrication 2017. In Proceedings of the 28th Annual International Solid Freeform Fabrication Symposium, Austin, TX, USA, 7–9 August 2017.
89. Mohammed, M.I.; Wilson, D.; Gomez-Kervin, E.; Vidler, C.; Rosson, L; Long, J. The recycling of E-Waste ABS plastics by melt extrusion and 3D printing using solar powered devices as a transformative tool for humanitarian aid. In Proceedings of the 29th Annual International Solid Freeform Fabrication Symposium, Austin, TX, USA, 13–15 August 2018.
90. Zhong, S.; Pearce, J.M. Tightening the loop on the circular economy: Coupled distributed recycling and manufacturing with recyclebot and RepRap 3-D printing. Resour. Conserv. Recycl. 2018, 128, 48–58.
91. Woern, A.L.; Pearce, J.M. Distributed Manufacturing of Flexible Products: Technical Feasibility and Economic Viability. Technologies 2017, 5, 71, doi:10.3390/technologies5040071.
92. Zander, N.E.; Gillan, M.; Burckhard, Z.; Gardea, F. Recycled polypropylene blends as novel 3D printing materials. Addit. Manuf. 2019, 25, 122–130.
93. Pringle, A.M.; Rudnicki, M.; Pearce, J. Wood Furniture Waste-Based Recycled 3-D Printing Filament. For. Prod. J. 2018, 68, 86–95, doi:10.13073/FPJ-D-17-00042.
94. Tian, X.; Liu, T.; Wang, Q.; Dilmurat, A.; Li, D.; Ziegmann, G. Recycling and remanufacturing of 3D printed continuous carbon fiber reinforced PLA composites. J. Clean. Prod. 2017, 142, 1609–1618, doi:10.1016/j.jclepro.2016.11.139.
95. King, D.L.; Babasola, A.; Rozario, J.; Pearce, J.M. Mobile Open-Source Solar-Powered 3-D Printers for Distributed Manufacturing in Off-Grid Communities. Chall. Sustain. 2014, 2, 18–27.
96. Gwamuri, J.; Franco, D.; Khan, K.Y.; Gauchia, L.; Pearce, J.M. High-Efficiency Solar-Powered 3-D Printers for Sustainable Development. Machines 2016, 4, 3.
97. Khan, K.Y.; Gauchia, L.; Pearce, J.M. Self-sufficiency of 3-D printers: Utilizing stand-alone solar photovoltaic power systems. Renew. Wind Water Solar 2018, 5, 5.
98. Woern, A.L.; Byard, D.J.; Oakley, R.B.; Fiedler, M.J.; Snabes, S.L.; Pearce, J.M. Fused Particle Fabrication 3-D Printing: Recycled Materials’ Optimization and Mechanical Properties. Materials 2018, 11, 1413.
99. Byard, D.J.; Woern, A.L.; Oakley, R.B.; Fiedler, M.J.; Snabes, S.L.; Pearce, J.M. Green fab lab applications of large-area waste polymer-based additive manufacturing. Addit. Manuf. 2019, 27, 515–525.
100. Schelly, C.; Anzalone, G.; Wijnen, B.; Pearce, J.M. Open-source 3-D printing technologies for education: Bringing additive manufacturing to the classroom. J. Vis. Lang. Comput. 2015, 28, 226–237.
101. Bailey, M.; Grieco, J.; Speights, A.; Weiss, R.G. 3D printing in the classroom and laboratory. J. Comput. Sci. Coll. 2015, 31, 183–184.

© 2019 by the authors. Licensee MDPI, Basel, Switzerland. This article is an open access article distributed under the terms and conditions of the Creative Commons Attribution (CC BY) license (http://creativecommons.org/licenses/by/4.0/).

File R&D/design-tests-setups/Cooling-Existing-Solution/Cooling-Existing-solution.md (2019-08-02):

#NOT-FEASIBLE:0 ## Reverse engineer cooling
Not feasible because we don't have one centrifuge of this kind.

#### Name: Santosh
#### Date:7-6-2019

## 1. Concept-for-solution:
We can replicate with fairly simple, off the sheleve components the existing solution.

## 2. To verify that we will do the following test:
Open it and set he design. Reverse engineering.

## 3. What are you going to measure
How it is implement.

## 4. Your experiment is successful if:
we can replicate quite exactly the same results with our DYI, or version.

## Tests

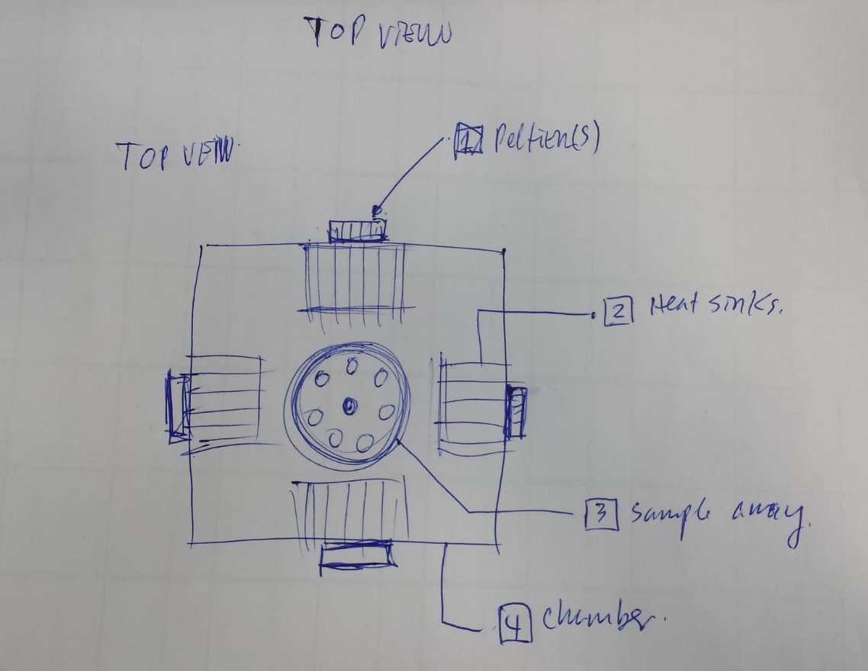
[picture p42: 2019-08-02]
R&D/design-tests-setups/Cooling-lid-03/02-test.jpeg

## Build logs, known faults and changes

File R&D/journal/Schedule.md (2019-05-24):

This document outlines what is expected of the projects and an initial schedule for the teams.

---

During the development of the projects we are going to put quite some emphasis into documentation, as a project is only properly open when its documentation allows others to:
- Feel welcome to contribute.
- Understand the current state of affairs in the project and make contributions.
- Replicate what is being developed and adapt it for local needs/wishes.

Documentation will be done in GitHub. Please make sure you're familiar with its basics by going through any of the many available tutorials online ([ex1](https://lab.github.com/), [ex2](https://help.github.com/en/articles/git-and-github-learning-resources), [ex3](https://git-scm.com/doc), [ex4](https://help.github.com/en/articles/set-up-git)).

Moreover, we will be developing scientific tools, which will hopefully reach a state where they can be:
- Calibrated and tested against "traditional tools".
- Published in a peer reviewed journal.

---
### Schedule

| Week | Products | Call  |
| --- | --- | ----- |
| Week 1 | GitHub repo + related_work.md + draft BoM | 1st call with mentor  |
| Week 2 | Order BoM + Dev Plan | 2nd call with mentor  |
| Week 3 | Contributing.md + CoC + updates on development | 3rd call with mentor  |
| Weeks 4-7 | Updates on development | 4-7 calls with mentor  |
| Week 8 | Demo | Group call  |

**Week1:**

- Set up a github repository for your project, cloning the structure of our [template repo](https://github.com/FOSH-following-demand/equipment_repository_template).

 - in case needed, learn the basics of GitHub using the many tutorials online:

 |Dedicated for researchers  | general audience tutorials |
 |--|--|
 |[Open Scapes](https://www.openscapes.org/) has chapters dedicated to GitHub use for scientists: [chapter 7](https://openscapes.github.io/series/github-pub.html) and [Chapter 8](https://openscapes.github.io/series/github-issues.html)| [tutorial 1](https://lab.github.com/)|
 |[Open Science MOOC](https://opensciencemooc.eu/) also has content dedicated [bring researchers to GitHub](https://eliademy.com/catalog/catalog/product/view/sku/02d7338a7e)|[tutorial 2](https://help.github.com/en/articles/git-and-github-learning-resources)|
 ||[tutorial 3](https://git-scm.com/doc)|
 ||[tutorial 4](https://help.github.com/en/articles/set-up-git)|

*Note: here are some other example repositories dealing with hardware: [actifield](https://github.com/trendinafrica/actifield), [LightM](https://github.com/vektorious/lightM).*

*Note 2: guidelines for a good readme by Mozilla can be found [here](https://mozilla.github.io/open-leadership-training-series/articles/opening-your-project/write-a-great-project-readme/) and a good example [here](https://github.com/KirstieJane/STEMMRoleModels)*

- Look up existing projects: find projects and resources available that can be useful for building your FOSH, so that you don't reinvent the wheel. Contact developers, maybe they would like to remotely contribute! Systematize these findings in related_work.md

- Draft a [bill of materials](https://github.com/FOSH-following-demand/equipment_repository_template/blob/master/hardware/BOM/BOM.md)

- First call with mentor

**Week2:**

- Order parts listed in the Bill of Materials

- Define a development plan following our template in dev_plan.md

- Second call with mentor

**Week3:**

- Add to the repository a contributing.md file and a code of conduct (Code_of_conduct.md) file

*Note: guidelines for a good code of conduct by Mozilla can be found [here](https://mozilla.github.io/open-leadership-training-series/articles/building-communities-of-contributors/write-a-code-of-conduct/) and for contributor guidelines, [here](https://mozilla.github.io/open-leadership-training-series/articles/building-communities-of-contributors/write-contributor-guidelines/)*

- Log advances and issues on repository - You can use GitHub's [project boards tool](https://help.github.com/en/articles/about-project-boards)

- Third call with mentor

**Weeks 4-7:**

- Log advances and issues on repository

- 4-7th calls with mentor

**Week 8:**

- Prepare a simple demo of your project
- Join the group call
- Celebrate :D

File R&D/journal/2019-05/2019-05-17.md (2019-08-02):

# Approach:
- Case study: Define design questions and problems based on production system, usage, etc.
  - Use the centrifuge as a case study for open hardware products.
  - An example of a question is: why there are machines with 24 slots if daily use only involves 6 samples
  (For )
  - Includes checking patent infringement
  - Study current open hardware solution

- Define target specs:
  - Based on understanding

#DONE:40 Open an issue about accquiring a disposed or not used centrifuge
- There might disposed usable equipment that we can use for the project.

#Doing:30 ## Design test cases
 - Design test cases for the DIY centrifuge we are going to buy (Polyfuge) to test its capacity to:
  > Separate microorganisms from media (from the canal water, for example)

  > DNA extraction

#DONE:20 ## Set target Specs/Hypotheses
 ### [Document with requirements](../../R&D/Specs-Req.md)
 - Specify what is the maximun number of samples slots needed in a normal day in a wet lab.
  > Assembly requirements

  > Materials that meet the standards to work in a wet lab.

#TODO: ## Set target Specs/Hypotheses
 - Design for the lowest torque design such that is able to spin at the required speed. For the low volume centrifuge.
 - It does not make sense to build one big machine to be used for both types of volumes.
 > The specs for high volumes are such that the motor holds high torques values, high weight, and high endurance, i.e. long times spinning at constant speed (max 4000 rpm). The mechanism for spinning is more expensive and demanding technically.

 > The specs for low volumes are motors able to spin at high speed (max 13 000 rpm), for low weight, and low torque.

#TODO: ## Design issues for outsourcing

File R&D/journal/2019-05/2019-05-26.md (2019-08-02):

#Hypothesis:10 ## Doubled motor centrifuge

# Value proposition scheme
=======
#Hypothesis:0 ## Doubled motor centrifuge
A model like the one in the drawing can be more cost effective...

## Jobs ,  role of the user: what are the common actions usually performed when using small and big centrifuges:

- Prepare the samples in the wet lab bench, usually they are mounted on a rack where you can use them.
- Then, transfer the samples to the centrifuge holder/rack.
- The samples have to be properly distributed on the centrifuge rack. This is a critical part in this process.
  - if this process is not properly done, users can cause a severe damage to the equipment, e.g, the centrifuge shaft can break as the samples plastic tubes. The machine usually makes intense sounds when this happens, and if the user is around, he/she has to stop inmediately the machine.
- The lid/s of the centrifuge has/have to be closed before pressing Run.
- Once is done, the user opens the lid/s and take away the samples from the centrifuge holder to the bench rack for next use.

## Pains : what bother us as users , and are critical on the good performance of the above mentioned jobs.
- (**critical**)There is no internal checking from the equipment that tell to the user that the samples are not properly distributed, before start centrifuging.
- There is no stop mechanism for unbalanced distributions.
- (**critical**)For small centrifuges (eppendurf commercially available) there is no an automatic sign from the equipment related with the  closing of the respective lids that need to be properly closed, before pressing RUN.
- At least for the case of small centrifuges, the machine is able to start runing even if the lid is not correctly closed.
  - if a lid is not properly closed can lead also to severe damage of the system.
- Consequently, users with no experience can easily break the machine.
- (**Not critical**)The transfer process of samples from the bench rack to the centrifuge and viceversa, could be a bit tedious, specially when working with many samples at once.

## Gains: what we would make the experience better for the above jobs.

- It would be nice and smart if an automatic mechanism is implemented in the small centrifuges that recognizes when a distribution of samples is unbalanced and also when the lids are not properly closed.
- It would be nice, for the case when working with may samples to have a rack that have a dual use, for centrifuge and bench manipulations.

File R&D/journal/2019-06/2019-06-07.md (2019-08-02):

# State of requirements
- [ ] State of BOM buying
- [ ] 3D printed parts
- [ ] Pick up centrifuges at Erasmus University

## Meeting with mentor

- Document in the readme that you're using an Atom package to track progress
- Take into account the deadline for buying stuff (20 june, max 25 june)
- Try to record/document with pictures the process of reverse ing of the broken centrifuges you got
- Let us know when you have created the issues with features to work on, so we can help you selecting and spreading through our networks
- Also share in the slack with the rest of the teams that may comment on it too

#Doing:10 Motor selection

#TODO:80 Check temperature measurement solution
[Link to the Responses from the form](https://docs.google.com/forms/d/1zq9jXL4ni4LQY3pLsI8-8exPlcGnMdUV0iULsLTLMks/edit#responses)

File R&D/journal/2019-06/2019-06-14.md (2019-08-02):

#Doing:20 Select motors
- Order a list of motors

#TODO:70 Print polyfuge stl parts
- [x] Rotor
- [ ] Jack plug holder
- [x] Knob

#DONE:10 Cutting of polyfuge parts

#DONE:0 Tear Down of the centrifuge eppendorf
- Document

#TEST:10 Vacuum formed casing

#Doing:60 Reverse Engineering plan for the 3 eppendorf

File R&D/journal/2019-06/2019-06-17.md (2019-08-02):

Doing:0 ## Circuit build
- Polyfuge board setup

- Use Fritzing for this
- [ ] Solder female jack for AC transformer

- [ ] Reverse engineer and redesign of polyfuge circuit

# References and tutorials
- [Arduino LCD Tutorial](https://howtomechatronics.com/tutorials/arduino/lcd-tutorial/).
- [LM 2596 DC -DC Buck converter | Adjustable step down module | specifications -Application](https://www.youtube.com/watch?v=QPntXt8Ea3s).

- [How does a brushless motor works](https://www.youtube.com/watch?v=uOQk8SJso6Q)
- [Control brushless motor with Arduino](https://www.youtube.com/watch?v=DTOK6CgXRXg)
- [Brushless motor control with Arduino Nano](https://www.youtube.com/watch?v=neU6vPDGOBA)

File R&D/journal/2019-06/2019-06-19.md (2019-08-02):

#DONE:30 Arduino LCD tutorial
[Basic circuit for LCD](https://howtomechatronics.com/tutorials/arduino/lcd-tutorial/).

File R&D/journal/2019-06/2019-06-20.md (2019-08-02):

#TODO: Solder teensy
We decided to

- [x] Check compatibility req with Arduino
- [x] Voltage input

#TODO: Test power supply
- [x] Set output voltage of power regulator to teensy specs 4.5 volts should be good.
- Connect female jack to switch
- Connect button

#TODO: Test LCD with teensy

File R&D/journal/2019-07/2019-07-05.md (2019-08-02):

Checklist circuit build
- [ ] Voltage regulator
- [ ] Speed controller
- [ ] IRSensor
- [ ] Rotary Encoder

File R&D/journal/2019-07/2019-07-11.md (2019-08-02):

# Issues:
- Teensy doesn't load the polyfuge program
  Learning: we should have tested this before
  Solutions:
    a- Use an Arduino board for instace Arduino Uno
    b- Modify the code so that it works on teensy

Set digital pins of Rotary encoder:

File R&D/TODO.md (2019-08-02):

#TODO:90 Physical model to determine forces for FEM analysis
- Describe and open the  issue with help wanted label (Jose)

We could design and update an issue, to crowd source it.
- Design the experiment and simulation.
Ideas for experiment: assume certain facts, and data for the model
> The centrifuges rotate at 4000 rpm with certain mass specifications and system behavior...

(Specify simulation scenario).
Consider software like [modelica](https://www.youtube.com/watch?v=-mvEUuc-sWE&ab_channel=StrangeLoop) for physic systems simulation.

#TODO:100 FEM Analysis of parts designed depending on physical model
- Big centrifuge design

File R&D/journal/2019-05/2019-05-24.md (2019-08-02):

# Dev plan
- order the closest solution to a commercial kit
- Setting up the requirements
- Setting target specifications
  -

#DONE:60 ## Form for lab to ask questions related to requirements:
(Jose) Document it as an issue in our repo

## Manufacturing contexts and ideas based on scale
- What scale are we talking about, what is an estimate volume, maybe or a percentage of current users, maybe just in the Netherlands.
- What is the scenario low volume, mid volume, high volume? what technologies are best suited. Towards commercial product
- Injection parts are going to be really complicated
- Outer casing could be vacuum formed.

#TEST:0 Vacuum forming which can be done in Delft
We can do it based on the kit we are going to buy.
  - Can it be done with recycled plastic? if you have agood stream of plastic, good quality of recycled plastic.

#TEST:20 ## Find if there are commercial standard casings that can be adapted
What are the specifications of size, volume, structure, embodiment.

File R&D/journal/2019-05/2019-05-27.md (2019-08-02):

#Doing:50 ## Web documentation properly organized
- Having the template ready (Carlos)

#DONE:50 ## First order of parts
We ordered the polyfuge model to start building and trying it out.

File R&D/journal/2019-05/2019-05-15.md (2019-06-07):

#Doing:40 ## Buy a polyfuge kit design
- [Buy to test in the context of daily use in wetlab](https://www.kickstarter.com/projects/1733191226/polyfuge-a-diy-open-source-microcentrifuge-for-eve)

# Design brief for wet lab centrifuges design

## Describe the product's vision
- Open Source centrifuge that improves the commonalization of components.
-

## User group
Describe the group of users that will use the product. Market segment to which we are going.
## Needs
- Access to equipment that is competitive, commercial grade(is a product not a design, that meet the standards) also open and easy to improve by anyone...
(An open hardware product)
- We need to centrifuge different volumes
  - up to 1.5ml
  - up to 50 ml

### Audience/ Users

### Jobs (Requirements)
- Needs to be compliant with [wet lab requirements](https://en.wikipedia.org/wiki/Wet_lab)

### Pains
- There are already a lot of open hardware projects for centrifuges and users don't know which to use, where to find it.
- The sources and quality of documentation is diverse
- The volume for centrifuges targeted currently in the solutions is for small volumes(until 1.5 ml)
- Not all users want to do a fully DIY centrifuge.
- available solutions are not yet scalable for even low volume production (ideally mid- high volume )
- There is no available open hardware solution for 50 ml
- Active patents don't allow to replicate /reuse those designs patented

### Gain creators:
- Centrifuge high volumes until 50 ml
- Centrifuge can be acquired as a
- Equipment can be acquired completely assembled and in mid to high volumes
- The centrifuge shares components and solutions with other equipment that uses similar components (electronics, etc.)

## Product (ProductBacklog)
What are the needs of the user group?
-

## Business Objectives
What goals do we have with the business?
What benefits do we look for within the organization?

## Competitors
What are the variants or alternatives to this product

## Sources of income
How can we monetize and generate revenue?
What do you need to capture, enter those sources?

## Cost factors
What are the costs for centrifuges?

# References:
- [What is Local Production](https://www.igi-global.com/dictionary/local-production/17360)
1. The strategy with sensitivity to place and scale in order to sustain local communities and provide new job opportunities while preserving the quality of the environment. Learn more in: Slow Fashion and Sustainability: The Luxury Impact
2. This involves the manufacture of ICT software and hardware within the country. Learn more in: ICT Policies in Africa
Find more terms and definitions using our Dictionary Search.

[Local production system:](https://www.igi-global.com/chapter/how-do-entrepreneurial-ecosystems-influence-growth-and-development/141416)
Is a territorially concentration of economic, political and social agents, performing related economic activities and presenting consistent articulation, interaction, co-operation and learning processes. It includes the stakeholders of private, public and profit sector.

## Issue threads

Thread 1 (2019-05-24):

Brief problem analysis and first review on the topic

jurra, 2019-05-24:
Hi all this is our first snapshot of what we have found in the preliminary research. Please comment and suggest changes. Lets start a discussion on the state of the ar of these machines.

# Design brief for wet lab centrifuges design

## Describe the product's vision
- Open Source centrifuge that improves the commonalization of components.
## User group
Describe the group of users that will use the product. Market segment to which we are going.
## Needs
- Access to equipment that is competitive, commercial grade(is a product not a design, that meet the standards) also open and easy to improve by anyone...
(An open hardware product)
- We need to centrifuge different volumes
  - up to 1.5ml
  - up to 50 ml

### Audience/ Users

### Jobs (Requirements)
- Needs to be compliant with [wet lab requirements](https://en.wikipedia.org/wiki/Wet_lab)

### Pains
- There are already a lot of open hardware projects for centrifuges and users don't know which to use, where to find it.
- The sources and quality of documentation is diverse
- The volume for centrifuges targeted currently in the solutions is for small volumes(until 1.5 ml)
- Not all users want to do a fully DIY centrifuge.
- available solutions are not yet scalable for even low volume production (ideally mid- high volume )
- There is no available open hardware solution for 50 ml
- Active patents don't allow to replicate /reuse those designs patented

### Gain creators:
- Centrifuge high volumes until 50 ml
- Centrifuge can be acquired as a
- Equipment can be acquired completely assembled and in mid to high volumes
- The centrifuge shares components and solutions with other equipment that uses similar components (electronics, etc.)

## Product (ProductBacklog)
What are the needs of the user group?
-

## Business Objectives
What goals do we have with the business?
What benefits do we look for within the organization?

## Competitors
What are the variants or alternatives to this product

## Sources of income
How can we monetize and generate revenue?
What do you need to capture, enter those sources?

## Cost factors
What are the costs for centrifuges?

# References:
- [What is Local Production](https://www.igi-global.com/dictionary/local-production/17360)
1. The strategy with sensitivity to place and scale in order to sustain local communities and provide new job opportunities while preserving the quality of the environment. Learn more in: Slow Fashion and Sustainability: The Luxury Impact
2. This involves the manufacture of ICT software and hardware within the country. Learn more in: ICT Policies in Africa
Find more terms and definitions using our Dictionary Search.

[Local production system:](https://www.igi-global.com/chapter/how-do-entrepreneurial-ecosystems-influence-growth-and-development/141416)
Is a territorially concentration of economic, political and social agents, performing related economic activities and presenting consistent articulation, interaction, co-operation and learning processes. It includes the stakeholders of private, public and profit sector.

Closed 2019-06-07.

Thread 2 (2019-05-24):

Centrifuge Idea

MakerTobey, 2019-05-24:
Hi team,
I just got pointed to the through André - awesome project! I am keen to see it progress.

In a brainstorming fashion I just thought it would be very practical to have a centrifuge that works with a kind of (open) tube rack for tubes that would allow you to click the entire rack into the centrifuge, so you would not have to transfer the tubes back and forth all the time for protocols that involve several short centrifugation steps.

Cheers,
Tobey

jurra, 2019-06-07:
Hi Tobey, I am really sorry for our late reply. Would you like to join as a collaborator?
We can add you to our slack channel and directly exchanging ideas there.
Your idea sounds great. Today we were putting together the ideas wehave been developing in [this format](https://github.com/FOSH-following-demand/Open-source-Centrifuge-for-WetLab/blob/master/R%26D/test-cards/Cooling-led-2.md). If is not too complicated for you you can also documented as such. I will add you to the repo as well as a contributor. :)

Cheers!

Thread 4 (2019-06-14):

Peltier cooling concept as an upgrade of Polyfuge

jurra, 2019-06-14:
# Peltier on led floating close to sample
#### Name: Santosh
#### Date:

## 1. Concept-for-solution:
The peltier doesn't touch the sample. It starts cooling when it rotates, air is cooled with the peltier and that air cools the sample. The concept the faster it rotates the faster it will cool down. Thermo couple will measure the temperature and will compare to the set value of temperature.
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

## 2. To verify that we will do the following test:
## Checklist for experiment:
Based on the temperature range (what thermo couple is able to measure), we decide the type of it.

## Materials:
- [K type](https://en.wikipedia.org/wiki/Thermocouple), should do the job. Is the cheapest and most commonly used.
- [Cooling kit that incldes peltier, heatsink, fan,and more.](https://www.amazon.de/dp/B01M5DX5KT?tag=tv-auto-20)
- Power Supply (Not specified yet)
## 3. What are you going to measure
## Checklist:
- [ ] How much data
- [ ] How much time does it takes

## 4. Your experiment is successful if:
- We are able to cool the samples in less than 5 minutes to the target temperature set by the user.
- The temperature of the samples remain constant.

# Implementation notes
## Usage considerations:
3. The chamber needs to be already cooled before we put the samples.
2. Therefore in this concept, the user would have to first cool the system,
3. Then open the led to place the sample.
4. And start centrifuging.

## Architecture and layout model test:
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

## How to measure temperature
**Options/Ideas:**

a. Wireless temperature sensor touching one of the samples, mounted on the rotor.

b. Meausre right after the cool process placing thermo coupler on top of the sample

## References
- [Building your own mini fridge](https://hackaday.com/2015/04/03/building-your-own-mini-fridge/).
- [Peltier Thermoelectric Cooler](https://www.youtube.com/watch?v=jCMDuTR-mqY&t=47s)
- [Peltier Module Cooling](https://www.youtube.com/watch?v=9Cuh2msd2lo).

# Ideas
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

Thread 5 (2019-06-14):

Speed improvement

jurra, 2019-06-14:
We are aiming for 15000 rpm for samples of 1.5ml.

jcmolloy, 2019-06-17:
Are you planning to use a metal casing and rotor? One of the features lacking in any open centrifuge at the moment is the ability to reach high speeds and contain the rotor in the event of it shearing off, because they either don't have a casing or it's made of quite thin acrylic. I saw safety emphasised in your design specs but I couldn't see documentation of casing materials yet, apologies if I missed it!

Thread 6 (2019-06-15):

Commercial centrifuge disassembly

jurra, 2019-06-15:
Hi everyone :smile:  we tear down an eppendorf.
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
[This is the link with the images](https://drive.google.com/drive/folders/13IaoEXw5r9--7KJN5DunTRCzpzE6lL5b?usp=sharing).

## I encourage you to think about why is it designed like this. Here are some notes and reflecting about it.
There are several characteristics that pop up:
- The rotor is a machined piece of metal, quite heavy and it has 24 holes for samples of 1.5ml.
- The motor is huge! It is quite big to be able to rotate such a heavy piece of metal. Imagine the torque and rotational inertia this baby generates.
- Along with that, this brings some safety issues related, and the control of the motor can be a challenge.
- I suspect that this same motor and circuitry can be used in other eppendorf models and they reuse the motor + circuitry, adding more circuits.

Any re-design ideas?

amchagas, 2019-06-16:
+1 for using Ifixit tools for teardowns :)
Now, in all seriousness, this tells us quite a few interesting things I think.

First, we should be very careful with this design (as you already mention) based on sheer force/speed of the motor. Also because from the photos, there is some high voltage going on in the board, and the motor most likely runs directly on 230V AC?

I don't know if this will be necessary for your design as well, but worth keeping in mind.

another thing is that a quick google leads to the developer of the centrifuge drive https://www.hanning-hew.com/en/products/driving/

And

https://www.hanning-hew.com/en/assets/template/Medien/Dateien/Downloads/Englisch/hew-brochure-centrifuge-en.pdf

Might be worth contacting them and seeing costs for this part? and then developing things around it? Maybe not ideal from the "vendor lock in" it will create, but nice to get an idea on manufacturing costs of these systems?

One question that I have is if you folks have an idea on how old that centrifuge was/is? when was it produced? Maybe technology has evolved since and one can use simpler designs/motors?

jurra, 2019-06-17:
Nice points @amchagas it seems like the technology is old. I will look in more details into your points. It is also good in general to understand also how these products and base technologies evolve :)

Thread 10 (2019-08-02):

Test: vacuum formed housing

JannesHN, 2019-08-02:
To be used in a true laboratory setting, the outer shell of the centrifuge should be able to be thoroughly cleaned. The current design has holes on the inside and a 3D printed shell will have all small pores where contaminants can accumulate.

A smooth one-piece outer shell can be cleaned easily. I want to try whether we can have a vacuum formed outer shell that can be placed over the current housing like this:
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

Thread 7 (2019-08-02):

Design: Smaller, 3D printable version

JannesHN, 2019-08-02:
We'd like to make a smaller housing for the centrifuge that is designed to keep all the inner parts exactly in place in a minimal volume.
The current version is build with both 3D printed parts and laser cut parts. For those who don't have a lasercutter at hand, a fully 3D printed design is a solution.

jurra, 2019-08-15:
# Design sprint for Polyfyge 2.0
Week 33
Participants:
- Jerry de Vos
- Jose Carlos Urra
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
## Design Principles
We are aiming for a mini centrifuge
### Architecture design principles:
- Avoid having as much floating components as possible.
    Solution:
    - Mount as much components as possible in the PCB:
      - Microcontroller board, Power Sitch, Power connection, Screen and Digital encoder

- Make the architecture design and placement of the components manufacturing agonostic(as much as possible).
  - This means that people should be able to fabricate the casing with a 3D printer, laser cutter, vacuum forming etc.

## Design requirements
- Add a mechanical switch for the led to ensure safety
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
- Part of the rotor should be visible (transparent).
- Use a teensy or similar solution that holds an SD card to store data about product usage, like cycles, etc.
- The PCB should be accessible via easy disassembly steps, ideally one step.
- Electronic connections should be robust and standard:
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
- PCB must facilitate ease of soldering.
- The electronics should be easily testable without having to assemble the whole product.
- Make the motor mount robust

## Tasks and tests:
- Make a preliminary PCB CAD module focused on architecture and component placement.
 - **Rationale**: We want to print the PCB prototype, or laser cut it to se how it fits the requirements above.
- Make CAD design focused on fast printability.
 - Print it and test it with new PCB CAD prototype.

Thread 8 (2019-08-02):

Feature: design: include cooling

JannesHN, 2019-08-02:
A good feature to add to the design is a coolingsystem that can cool the samples down to 4 degrees (Celsius, obviously). Our current idea is just keep the chamber in which the rotor rotates as small as possible and cool the whole thing with a peltier ellement and use a thermocouple as sensor. We have a peltier ellement, heat sinks and fans. Like this right now:
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

jurra, 2019-08-02:
First try:
we tried measured the temperature after 10 mins and the samples went 28 to 17 degrees celcius. This setup didn't work, becaus we have to go down to 4 celcius. We have to improve the insulation, or think of a different cooling system. But is good to build this before even trying to build a pcb to control the peltier.
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

amchagas, 2019-08-02:
Hi,
It is not clear to me from the photos how you are removing heat from the chamber with the samples. Is the idea that the peltier cools down the heat dissipator and the fan is used to blow air through it, which then gets cooled air into the chamber?

Did you happen to test how cold the heat dissipator gets if the fan sitting on it is not on? This would be a nice way to know if this peltier plus heatsinks and fans is a good combo... In other words if running without the chamber, the system doesn't go below 4c then it might be you only need a beefier peltier+power supply? From the link have a 12V 5A peltier, there are other options available that can take more power in the same area (here is an [rs search](https://uk.rs-online.com/web/c/hvac-fans-thermal-management/electronics-heating-cooling/peltier-modules/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,4294373917,4294371825,4294801486,4294351349,4294351346,4294856768,4294801493,4294738766,4294705222,4294705239,4294377977,4294351332,4294705216,4294705205,4294362460,4294738742,4294722580,4294705203,4294705229,4294801508,4294705217,4294738762,4294818914,4294818918,4294705233) with more options), maybe this is the easiest way to test, without having to change much of the design? Just swapping the peltier?

A couple of things I can think of that might help, or might be absolute non-sense (I didn't make my mind about it yet :P ):

Ultimately, you want your samples to be at that temperature, correct? would it be possible to cool down to rotor by induction? As in attach the peltier to the motor casing (which doesn't move) and hope to cool down the rotor so that in turn the samples are cold too? Again, maybe this is a terrible idea, since the motor would be cooled down too, but maybe it doesn't affect it that much?

amchagas, 2019-08-02:
also, on the peltier swapping idea, you might need a new circuit/power supply to drive it... but this is relatively straight forward to buy, or to design...

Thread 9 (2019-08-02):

Feature design: safety features

JannesHN, 2019-08-02:
The current version has an IR proximity sensor to check whether the lid is closed. ..and we took that off because it was too flimsy, so we have not safety feaure at all right now.

Things that we should be adding:
- a simpler sensor for the closing of the lid.
- a more robust lid. Not PMMA, but metal one would be nice.
- a system that checks wether the rotor is well balanced and can stop the spinning when it's not.

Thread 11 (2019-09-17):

Creating FreeCAD CAD files

luzpaz, 2019-09-17:
I was wondering if you'd be interested in this idea. Over at [FreeCAD](https://www.freecadweb.org/) forums we've been doing this thing where we reach out to open source hardware projects offering to create CAD files for them in FreeCAD format. It gives the community a nice challenge to model and sharpen skills; it also helps us find bugs which we hopefully fix :)

Anyway, was wondering if you'd be interested ?

jurra, 2019-09-17:
Sounds great!

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

<https://www.avast.com/sig-email?utm_medium=email&utm_source=link&utm_campaign=sig-email&utm_content=webmail>
Virus-free.
www.avast.com
<https://www.avast.com/sig-email?utm_medium=email&utm_source=link&utm_campaign=sig-email&utm_content=webmail>
<#DAB4FAD8-2DD7-40BB-A1B8-4E2AA1F9FDF2>

luzpaz, 2019-09-17:
@jurra right now we're working on 2 projects:
* [Recreating a Libre/Open Source Otoscope in FreeCAD](https://forum.freecadweb.org/viewtopic.php?f=8&t=38643) (mostly complete)
* [Converting the Libre/Open Source Camera:AXIOM in FreeCAD](https://forum.freecadweb.org/viewtopic.php?f=8&t=39387) (initial stages)

When we're relatively complete with those then we can introduce this project ?

jurra, 2019-09-17:
Sounds good :)

<https://www.avast.com/sig-email?utm_medium=email&utm_source=link&utm_campaign=sig-email&utm_content=webmail>
Virus-free.
www.avast.com
<https://www.avast.com/sig-email?utm_medium=email&utm_source=link&utm_campaign=sig-email&utm_content=webmail>
<#DAB4FAD8-2DD7-40BB-A1B8-4E2AA1F9FDF2>

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

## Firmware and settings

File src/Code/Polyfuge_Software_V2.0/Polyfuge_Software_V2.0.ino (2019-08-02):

/*
 *  Polyfuge_Software_V1.0.ino - Polyfuge control software.
 *  Copyright (C) 2018 Jason Wu. All Rights Reserved.
 *
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
 *  You should have received a copy of the GNU General Public License along with
 *  the Polyfuge control software.  If not, see <http://www.gnu.org/licenses/>.
 */

/*
 * Pins on Board
 * LCD: 12,11,5,4,3,2
 * ESC: 13
 * Optical: A0
 * Rotary Encoder: 6,9
 * Button: 7
*/

//add libraries
#include <PinChangeInt.h>
#include <Servo.h>
#include <LiquidCrystal.h>

//define pins
int opticalPin = A0;
#define encoderPinA 6
#define encoderPinB 9
int buttonPin = 7;
int escPin = 13;

//constants
LiquidCrystal lcd(12,11,5,4,3,2);
Servo esc;

//input variables
int encoderVal = 0;
int buttonState;
int previousButtonState = HIGH;
int opticalState;

//modes
boolean modeSelect = true;
boolean rpmSelect = false;
boolean minuteSelect = false;
boolean secondSelect = false;
boolean confirmSelect = false;
boolean runModeSetup = false;
boolean runMode = false;

//calculation variables
int option;
int rpm;
long minutes;
long seconds;
long runTime;
unsigned long startTime;
unsigned long endTime;

//display variables
int displayMinutes;
int displaySeconds;

//confirm variables
boolean confirmStatus = false;

//previous calculation variables
int previousOption = -1;
long previousrpm = 1;
long previousMinutes = 1;
long previousSeconds = 1;
boolean previousConfirmStatus = true;
int previousDisplayMinutes = -1;
int previousDisplaySeconds = -1;

//motor variables
int escValNeutral = 1000;


void setup() {

  //pinModes
  pinMode(opticalPin,INPUT);
  pinMode(buttonPin,INPUT_PULLUP);
  pinMode(encoderPinA,INPUT_PULLUP);
  pinMode(encoderPinB,INPUT_PULLUP);
  pinMode(escPin,OUTPUT);

  //attach interrupts
  attachPinChangeInterrupt(encoderPinA, readEncoder, CHANGE);

  //arm motor
  esc.attach(escPin);
  esc.writeMicroseconds(escValNeutral);

  //start lcd
  lcd.begin(16,2);
  lcd.clear();

  //welcome text
  lcd.setCursor(0,0);
  lcd.print("Welcome to");
  lcd.setCursor(0,1);
  lcd.print("Polyfuge");
  delay(3000);

  //loading countdown
  lcd.clear();
  lcd.setCursor(0,0);
  lcd.print("Loading in");
  lcd.setCursor(0,1);
  lcd.print("                ");
  lcd.setCursor(0,1);
  lcd.print("3 second(s)");
  delay(1000);
  lcd.setCursor(0,1);
  lcd.print("2");
  delay(1000);
  lcd.setCursor(0,1);
  lcd.print("1");
  delay(1000);

  //set up modeSelect screen
  if(modeSelect == true){
    lcd.setCursor(0,0);
    lcd.print("                ");
    lcd.setCursor(0,0);
    lcd.print("  Timed Run");
    lcd.setCursor(0,1);
    lcd.print("                ");
    lcd.setCursor(0,1);
    lcd.print("  Quick Spin");
    }
}

void loop() {

  //modeSelect and read encoder + mark selection
  if(modeSelect == true){

    if(encoderVal > 1){
      encoderVal = 1;
      }
      if(encoderVal < 0){
        encoderVal = 0;
        }

    //show selected option on LCD
    option = encoderVal;
    if(option != previousOption){
      if(option == 0){
        lcd.setCursor(0,0);
        lcd.print(">");
        lcd.setCursor(0,1);
        lcd.print(" ");
        }
        else{
          lcd.setCursor(0,1);
          lcd.print(">");
          lcd.setCursor(0,0);
          lcd.print(" ");
          }
      }
      previousOption = option;
    }

  //buttonPressed Mode switch to rpmSelect or quickSpin
  if(modeSelect == true){
    buttonState = digitalRead(buttonPin);

    //user selects timed run
    if(buttonState == LOW && previousButtonState == HIGH && option == 0){

      //set up rpmSelect screen
      previousOption = -1;
      encoderVal = 0;
      lcd.clear();
      lcd.setCursor(0,1);
      lcd.print("Microseconds");

      //turn off modeSelect and turn on rpmSelect
      modeSelect = false;
      rpmSelect = true;
      }

    //user selects quick spin
    if(buttonState == LOW && previousButtonState == HIGH && option == 1){

      //set up screen for quickSpin
      lcd.clear();
      lcd.setCursor(0,0);
      lcd.print("Quick spin in");
      lcd.setCursor(0,1);
      lcd.print("progress.");

      //turn on motor
      esc.writeMicroseconds(1300);
      delay(800);

      //turn off motor
      esc.writeMicroseconds(escValNeutral);

      //set up screen for modeSelect
      lcd.setCursor(0,0);
      lcd.print("                ");
      lcd.setCursor(0,0);
      lcd.print("  Timed Run");
      lcd.setCursor(0,1);
      lcd.print("                ");
      lcd.setCursor(0,1);
      lcd.print("  Quick Spin");

      //reset variables
      previousOption = -1;
      encoderVal = 0;
      }
      previousButtonState = buttonState;
      delay(50);
    }

  //read rotary encoder and display rpm + read button
  if(rpmSelect == true){
    //check encoderVal for max + min out
    if(encoderVal > 90){
      encoderVal = 90;
      }
      if(encoderVal < 0){
        encoderVal = 0;
        }

    //rewrite screen if rpm changed
    rpm = encoderVal + 1235;
    if(rpm != previousrpm){
      lcd.setCursor(0,0);
      lcd.print("                ");
      lcd.setCursor(0,0);
      lcd.print(rpm);
      }
      previousrpm = rpm;
  }

  //button pressed mode switch from rpm to minuteSelect
  if(rpmSelect == true){
    buttonState = digitalRead(buttonPin);
    if(buttonState == LOW && previousButtonState == HIGH){
      //motor to neutral
      esc.writeMicroseconds(0);
      rpmSelect = false;
      minuteSelect = true;
      encoderVal = 0;
      lcd.clear();
      lcd.setCursor(0,1);
      lcd.print("Minute(s)");
      }
      previousButtonState = buttonState;
      delay(50);
    }

    //read rotary encoder and display minutes + read button
    if(minuteSelect == true){
      //check encoderVal for max + min out
      if(encoderVal > 15){
        encoderVal = 15;
        }
        if(encoderVal < 0){
          encoderVal = 0;
          }

      //rewrite screen if minute changed
      minutes = encoderVal;
      if(minutes != previousMinutes){
        lcd.setCursor(0,0);
        lcd.print("                ");
        lcd.setCursor(0,0);
        lcd.print(minutes);
        }
      previousMinutes = minutes;
      }

  //button pressed mode switch from minuteSelect to secondSelect
  if(minuteSelect == true){
    buttonState = digitalRead(buttonPin);
    if(buttonState == LOW && previousButtonState == HIGH){
      minuteSelect = false;
      secondSelect = true;
      encoderVal = 0;
      lcd.clear();
      lcd.setCursor(0,1);
      lcd.print("Second(s)");
      }
      previousButtonState = buttonState;
      delay(50);
    }

    //read rotary encoder and display seconds + read button
    if(secondSelect == true){
      //check encoderVal for max + min out
      if(encoderVal > 59){
        encoderVal = 59;
        }
        if(encoderVal < 0){
          encoderVal = 0;
          }

      //rewrite screen if seconds changed
      seconds = encoderVal;
      if(seconds != previousSeconds){
        lcd.setCursor(0,0);
        lcd.print("                ");
        lcd.setCursor(0,0);
        lcd.print(seconds);
        }
      previousSeconds = seconds;
      }

  //button pressed mode switch from secondSelect to confirmSelect
  if(secondSelect == true){
    buttonState = digitalRead(buttonPin);
    if(buttonState == LOW && previousButtonState == HIGH){
      secondSelect = false;
      confirmSelect = true;
      encoderVal = 0;
      lcd.clear();
      lcd.setCursor(0,1);
      lcd.print("Ready to Spin?");
      }
      previousButtonState = buttonState;
      delay(50);
    }

    //read rotary encoder and display confirm + read button
    if(confirmSelect == true){
      //check encoderVal for max + min out
      if(encoderVal > 1){
        encoderVal = 0;
        }
        if(encoderVal < 0){
          encoderVal = 1;
          }

      //map confirmStatus
      if(encoderVal == 1){
        confirmStatus = true;
        }
        else{
          confirmStatus = false;
          }

      //rewrite screen if seconds changed
      if(confirmStatus != previousConfirmStatus){
        lcd.setCursor(0,0);
        lcd.print("                ");
        lcd.setCursor(0,0);
        if(confirmStatus == true){
          lcd.print("Yes");
          }
          else{
            lcd.print("No");
            }
        }
      previousConfirmStatus = confirmStatus;
      }

  //button pressed mode switch from confirmSelect to runModeSetup
  if(confirmSelect == true){
    buttonState = digitalRead(buttonPin);
    if(buttonState == LOW && previousButtonState == HIGH && confirmStatus == true){
      confirmSelect = false;
      runModeSetup = true;
      encoderVal = 0;
      lcd.clear();
      lcd.setCursor(0,0);
      lcd.print("Preparing for");
      lcd.setCursor(0,1);
      lcd.print("run...");
      }

      //reset to modeSelect
      else if(buttonState == LOW && previousButtonState == HIGH && confirmStatus == false){
        //reset variables
        encoderVal = 0;
        rpm = 0;
        minutes = 0;
        seconds = 0;
        confirmStatus = false;
        previousrpm = 1;
        previousMinutes = 1;
        previousSeconds = 1;
        previousConfirmStatus = true;

        //mode switch
        confirmSelect = false;
        modeSelect = true;

        //set modeSelect screen
        lcd.clear();
        lcd.setCursor(0,0);
        lcd.print("                ");
        lcd.setCursor(0,0);
        lcd.print("  Timed Run");
        lcd.setCursor(0,1);
        lcd.print("                ");
        lcd.setCursor(0,1);
        lcd.print("  Quick Spin");
        }
      previousButtonState = buttonState;
      delay(50);
    }

  //reset variables + setup for run
  if(runModeSetup == true){

    //calculate run time (in milliseconds)
    runTime = (((minutes*60)+seconds)*1000);

    //reset variables
    encoderVal = 0;
    minutes = 0;
    seconds = 0;
    confirmStatus = false;
    previousrpm = 1;
    previousMinutes = 1;
    previousSeconds = 1;
    previousConfirmStatus = true;

    //give countdown for run
    lcd.clear();
    lcd.setCursor(0,0);
    lcd.print("Run Starting in:");
    lcd.setCursor(0,1);
    lcd.print("3 Second(s)");
    delay(1000);
    lcd.setCursor(0,1);
    lcd.print("2");
    delay(1000);
    lcd.setCursor(0,1);
    lcd.print("1");
    delay(1000);

    //switch to runMode
    runModeSetup = false;
    runMode = true;
    lcd.clear();
    lcd.setCursor(0,0);
    lcd.print("    Minute(s)");
    lcd.setCursor(0,1);
    lcd.print("    Second(s)");
  }

  //runMode
  if(runMode == true){

    //set time reference with millis
    startTime = millis();
    endTime = startTime;

    //turn motor on
    esc.writeMicroseconds(rpm);

    //run motor until time is up
    while(((endTime-startTime) <= runTime) && runMode == true){

      //calculate display minutes + display seconds
      displayMinutes = (((runTime-(endTime-startTime))/1000)/60);
      displaySeconds = (((runTime-(endTime-startTime))/1000)%60);

      //display minutes + seconds
      if(displayMinutes != previousDisplayMinutes){
        lcd.setCursor(0,0);
        lcd.print("    ");
        lcd.setCursor(0,0);
        lcd.print(displayMinutes);
        }
      if(displaySeconds != previousDisplaySeconds){
        lcd.setCursor(0,1);
        lcd.print("    ");
        lcd.setCursor(0,1);
        lcd.print(displaySeconds);
        }

      //check for opticalPin state, if optical state is low (lid is open so terminate run)
      // opticalState = digitalRead(opticalPin);
      // if(opticalState == HIGH){
      //
      //   //turn off run mode
      //   runMode = false;
      //
      //   //turn motor off
      //   esc.writeMicroseconds(escValNeutral);
      //
      //   //give error text
      //   lcd.clear();
      //   lcd.setCursor(0,0);
      //   lcd.print("Lid Opened");
      //   lcd.setCursor(0,1);
      //   lcd.print("Run Terminated");
      //   delay(5000);
      //
      //   //set up mode select screen + mode
      //   modeSelect = true;
      //   lcd.clear();
      //   lcd.setCursor(0,0);
      //   lcd.print("                ");
      //   lcd.setCursor(0,0);
      //   lcd.print("  Timed Run");
      //   lcd.setCursor(0,1);
      //   lcd.print("                ");
      //   lcd.setCursor(0,1);
      //   lcd.print("  Quick Spin");
      //   }

      //check for buttonPin state, if buttonPin state is high, then user cancelled run
      buttonState = digitalRead(buttonPin);
      if(buttonState == LOW){

        //turn off run mode
        runMode = false;

        //turn motor off
        esc.writeMicroseconds(escValNeutral);

        //give error text
        lcd.clear();
        lcd.setCursor(0,0);
        lcd.print("Button Pressed");
        lcd.setCursor(0,1);
        lcd.print("Run Terminated");
        delay(5000);

        //set up modeSelect screen + mode
        modeSelect = true;
        lcd.clear();
        lcd.setCursor(0,0);
        lcd.print("                ");
        lcd.setCursor(0,0);
        lcd.print("  Timed Run");
        lcd.setCursor(0,1);
        lcd.print("                ");
        lcd.setCursor(0,1);
        lcd.print("  Quick Spin");
        }

      //reset endTime + display time values
      previousDisplayMinutes = displayMinutes;
      previousDisplaySeconds = displaySeconds;
      endTime = millis();
      }
      if(runMode == true){

      //turn off run mode
      runMode = false;

      //turn off motor
      esc.writeMicroseconds(escValNeutral);

      //write completed screen
      lcd.clear();
      lcd.setCursor(0,0);
      lcd.print("Run Status:");
      lcd.setCursor(0,1);
      lcd.print("Completed");
      delay(3000);

      //reset values
      previousDisplayMinutes = -1;
      previousDisplaySeconds = -1;

      //set up modeSelect screen
      lcd.clear();
      lcd.setCursor(0,0);
      lcd.print("                ");
      lcd.setCursor(0,0);
      lcd.print("  Timed Run");
      lcd.setCursor(0,1);
      lcd.print("                ");
      lcd.setCursor(0,1);
      lcd.print("  Quick Spin");

      //switch to rpm select
      modeSelect = true;
      }
    }
}

//Read Encoder Interrupt
void readEncoder(){
  if(digitalRead(encoderPinA) == HIGH){
    if(digitalRead(encoderPinB) == HIGH){
      encoderVal--;
      }
      else{
        encoderVal++;
      }
    }
  }

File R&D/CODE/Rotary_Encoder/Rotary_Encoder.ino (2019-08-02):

/*
 * MARK VAN VEGGEL
 * ARDUINO LCD MENU V0.1
 * YOUTUBE.COM/AMPSOURCE
 *
 */

#include <OneButton.h>
#include <Encoder.h>
#include <Wire.h>
#include <LCD.h>
#include <LiquidCrystal.h>

//#include <LiquidCrystal_I2C.h>

//LiquidCrystal_I2C  lcd(0x27,2,1,0,4,5,6,7);
LiquidCrystal lcd(12,11,5,4,3,2);


// ROTARY ENCODER
long oldPosition  = 0;
int encoderDTpin = 6;
int encoderCLKpin = 9;
Encoder myEnc(encoderDTpin, encoderCLKpin);

int buttonPin = 7;
OneButton button0(buttonPin, true);


// MENU ARRAY
// First number in array = amount of menu items in root layer. Same goes for next layer. (Example: first value in array is 4. This means Layer 0 has 4 menu items. Layer 1 has only 2 menu items.)
// First number infront of menu text is the layer number that item points to. (Example: 1_Rotation points to Layer 1)
// Second number infront of menu text is the number of the value connected to that menu item in the values array. (Example: 15Direction points to position 5 in the values array)

String menu[] = {"4","1__Rotation","056Active","3__Watches","4__Item4",       // Layer 0
                 "3","100Rotations","105Direction","109Speed",                // Layer 1
                 "3","256Active","2__Item2.2","2__Item2.3",                    // Layer 2
                 "4","4__Watch 1","3__Watch 2","3__Watch 3","3__Watch 4",     // Layer 3
                 "2","4__Item3.1.1","4__Item3.1.2"};                          // Layer 4

// VALUES ARRAY
// TYPES, 1 numeric / 2 character value range
// 1 - type,value,increments,min,max
// 2 - type,starting value in options array,lowest value options array,max value options array
int values[] = {1,11,25,50,1450, //0-4 WATCH1
                2,2,0,2,         //5-8
                1,600,25,75,600, //9-13

                1,11,25,50,1450, //14-18 WATCH2
                2,2,0,2,         //19-22
                1,600,25,75,600, //23-27

                1,11,25,50,1450, //28-32 WATCH3
                2,2,0,2,         //33-36
                1,600,25,75,600, //37-41

                1,11,25,50,1450, //42-46 WATCH4
                2,2,0,2,         //47-50
                1,600,25,75,600, //51-55

                2,4,3,4,         //56-59 WATCH1 ACTIVE
                2,4,3,4,         //60-63 WATCH2 ACTIVE
                2,4,3,4,         //64-67 WATCH3 ACTIVE
                2,4,3,4};        //68-71 WATCH4 ACTIVE


String options[] = {"CW","CCW","MIX",
                    "No","Yes"};

// Custom character for LCD.
byte cursor[8] = {
  0b10000,
  0b10000,
  0b01000,
  0b00110,
  0b01000,
  0b10000,
  0b10000,
  0b00000
};

byte watch[8] = {
  0b01110,
  0b01110,
  0b11011,
  0b10001,
  0b10001,
  0b11011,
  0b01110,
  0b01110
};


int currentType = 0;
int value = 0;
int numIncr = 0;
int Min = 0;
int Max = 0;

int currentLayer = 0;
int lastLayer = 99;
int currentLength = menu[0].toInt();
int currentPosition = 0;
int currentSelect = 1;
int currentChange = 0;
String currentPress = "";
float currentlcdLayerFloat = 0;
int currentlcdLayer = 0;
int lastlcdLayer = 0;
int lcdUpdated = 0;
int currentLine = 0;
int cursorLayer = 0;
int cursorPosition = 0;
int valueLength = 0;

/*
int homeScreen = 1;

String currentTime = "00:00:00";
String lastTime = "00:00:00";
String temptime = "00";
String currentDate = "";

int watch1active = values[56] - 3;
int watch2active = values[60] - 3;
int watch3active = values[64] - 3;
int watch4active = values[68] - 3;
int watch1rotations = 0;
int watch2rotations = 0;
int watch3rotations = 0;
int watch4rotations = 0;
int watch1left = values[1];
int watch2left = values[15];
int watch3left = values[29];
int watch4left = values[43];
String temprotationsleft = "";
*/


void setup() {
  Serial.begin(9600);

  // Map rotary button to actions single and doubleclick.
  button0.attachClick(singleClick);
  button0.attachDoubleClick(doubleClick);

  lcd.begin (16,2);
  lcd.setBacklightPin(3,POSITIVE);
  lcd.setBacklight(HIGH);
  lcd.home();

  // Create the custom character.
  lcd.createChar(0, cursor);
  lcd.createChar(1, watch);

  lcd.setCursor (2,0);
  lcd.print("Watch Winder");
  delay(1000);
  clearLine(0);

  // Set the select cursor on the first line.
  cursorLayer = 0;
  lcd.setCursor (0,cursorLayer);
  writeCursor();

}

void loop() {

    // Listen to button presses.
    button0.tick();

    // Listen if the rotary encoder moves.
    rotary_check();

    // Print the LCD menu.
    lcdMenu();

}

void singleClick() {

  // IF current layer number is the same as redirect layer number, we stay on the same layer
  // AND no item is selected in the menu
  // AND the selected item has a redirect to another layer
  if(currentLayer == menu[currentPosition + currentSelect].substring(0,1).toInt() && menu[currentPosition + currentSelect].substring(1,3) != "__" && currentPress == ""){

    currentPress = menu[currentPosition + currentSelect].substring(3);
    currentChange = menu[currentPosition + currentSelect].substring(1,3).toInt();

    Serial.println("Currentpress: " + currentPress);

    currentType = values[currentChange];
    value = values[currentChange + 1];

    // Type select change is numeric
    if(currentType == 1){
      Min = values[currentChange + 3];
      Max = values[currentChange + 4];
      numIncr = values[currentChange + 2];

      Serial.println("Currentvalue: " + String(value));
      Serial.println("Increments: " + String(numIncr));
      Serial.println("Min: " + String(Min));
      Serial.println("Max: " + String(Max));


      valueLength = String(value).length();

    // Type select change is character range
    } else if(currentType == 2){
      Min = values[currentChange + 2];
      Max = values[currentChange + 3];

      Serial.println("Currentvalue: " + options[value]);
      Serial.println("Options: ");

      for (int i=Min; i <= Max; i++){
        Serial.println(options[i]);
      }

      valueLength = options[value].length();

    }

    clearSelect();
    cursorPosition = 15 - valueLength;
    lcd.setCursor(cursorPosition,cursorLayer);
    writeCursor();

  // ELSE IF something is selected in the menu, and the button is pressed again. We deselect the item.
  } else if(currentPress != ""){

    currentValues();
    currentPress = "";
    currentChange = 0;

    clearChar(cursorPosition,cursorLayer);
    lcd.setCursor(0,cursorLayer);
    writeCursor();

  // IF nothing is selected and nothing will be deselected, move to the redirect layer listed in the first position of the array.
  } else {

    currentLayer = menu[currentPosition + currentSelect].substring(0,1).toInt();
    currentSelect = 1;
    currentlcdLayerFloat = 0;
    currentlcdLayer = 0;
    lastlcdLayer = 0;

    clearSelect();
    cursorLayer = 0;
    lcd.setCursor (0,cursorLayer);
    writeCursor();

  }

}
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

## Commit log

2019-06-08 cooling peltier system bom
2019-06-08 Update BOM for cooling
2019-06-08 update file location on cooling led -02 solution
2019-06-08 Documentation of tests setup
    [4-inch-fan.stl, V2_Rotor.stl, cover.stl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]
2019-06-14 Updated documentation week 6
    [blade.scad, fan-rotor.scad]
2019-06-21 Circuit build documentation
2019-06-28 Arduino sketches tests
2019-07-06 calculations and workflow
    [calculations.xlsx]
2019-07-12 Panel LCD Arduino code example
2019-07-17 Refactored documentation
    [Back Panel.stl, Base.stl, Front Panel.stl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]
2019-07-24 updated documentation
    [coolingBom.ods]
2020-03-20 Files from jannes_dev with stl files (3D printing) and .ai files (for lasercutting)
    [knob v3.FCStd, knob3.stl]
2020-03-20 More freeCAD files for the new centrifuge design
    [PCB.FCStd, rotor.FCStd, sheet model_no cut.FCStd]

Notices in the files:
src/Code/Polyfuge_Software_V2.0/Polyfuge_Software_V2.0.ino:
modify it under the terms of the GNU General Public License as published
